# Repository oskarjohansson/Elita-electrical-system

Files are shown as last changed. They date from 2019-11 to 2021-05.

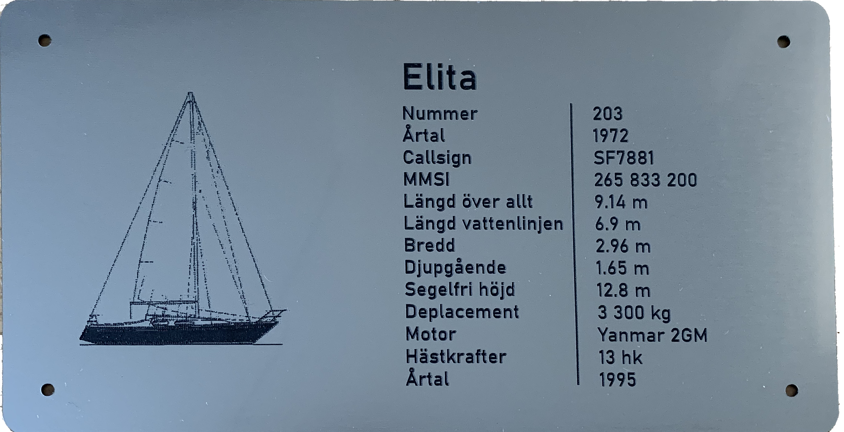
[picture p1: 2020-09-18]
hardware/control-panel/infosign.png

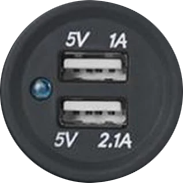
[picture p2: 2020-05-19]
hardware/control-panel/usb_outlet.png

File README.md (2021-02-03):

# Elita power distribution
> Created by Oskar Johansson 

This project is to refine the electrical system on the sailboat *Elita*. 

## Background

> A short background of the project. 

*Elita* was bought 2019 and had a relative good electrical system, but with poorly documentation. Since one of the complex part of a boat is the electrical system, the need of a reliable and easy system is important and there exists few power distribution system that is affordable. Then practical problems like have to wire everything through a panel to switch on and off seems quite old-fashioned.  

## Goal

> The goal of the project is 

The aim for this project is to simplify the wiring and make it possible for non-electrical-engineer to troubleshoot the system, like my brothers. 

The project will also aim to make it easier to do maintenance, like having a connector to all devices to make it easy to just unplug it without having to remove any cable. 

The project will also target one of the issues of the electrical system on a boat, the wire length. Since the voltage is 12 V, the voltage drop will affect the efficiency a lot when the wires become long. Together with that you want a control panel that is easily accessible the wiring become both long and complex. 

## Directories 

> The directories of the project. 

```python
Elita-electrical-system
├── documents                 # Manuals, ISO-documents, etc.       
│   └── datasheets            # Datasheet for components.
├── hardware                  # Schematics, pcbs, etc.
│   ├── battery-protection    # >100 A voltage protection for battery 
│   ├── cad                   # All CAD files 
│   ├── control-panel         # The control panel where all power switches are
│   ├── electrical-system     # Summary of the whole system
│   ├── flyback-protection    # To use in series of DC-motors to protect electrical system from flyback-currents.
│   ├── gerber                # Common folder for all gerber-files.
│   ├── ideal-diode           # An ideal diode circuit to charge the start battery everytime the bulk batteries is more charged.
│   ├── led-dimmer            # A simple dimmer for LED strips using a rotate encoder and mosfet
│   ├── libraries             # Project specific library.
│   ├── mount-panel           # A panel to mount the power distribution boards on.
│   ├── mppt-solar-charger    # A new controller to be used instead of the PWM controller.
│   ├── power-connector       # A simple power connector with M5 connectors. 
│   ├── power-distribution    			# Distribute power through mosfets and switches.
│   ├── power-distribution-complete		# Distribute all power through mosfets and switches.
│   ├── powersplitter         # In-line to split up the power-line.
│   ├── schematic             # All electrical schematics.
│   └── shorepower            # Schematic over how the shorepower should be connected according to complient ISO.
├── img                       # Images 
└── software                  # Firmwares
    └── led_dimmer            # Fiwmare for the led dimmer. 
```

# System 

> Here will the description of the system be. 

## Requirements

> The requirements of the system. 

- Follow ISO-standard, here ISO-10133 and ISO-13297
- Easy to use
- Lowest voltage drop possible
- No heat issue
- Integrated fuse
- Power meter 
- Easy to debug 
- Input from solar panel

## System architecture

> The architecture of the system. 

```python
├── Start battery           			# Must always be top charged.   
|	^
|	|
|	Ideal diode 						# To also charge the start battery from solar panel. 
|	^
|	|
└── House battery           			# Firmwares
    └── 120 A fuse          			# A resettable fuse
        ├── Fuse holder					# For things that shouldn't be switched off, like heater.
        |   └── Heater					# The heater has a cooldown process. 
	    └── Battery protection          # To protect from UV and be able to turn on/off from far away. 
	    	├── Fuse holder				# For things that has an integrated switch, like lighting. 
            |	├── Engine				# Everything that has to do with the engine.
            	|
                |
            |   └── Internal lights		# Has a switch on it.  
	    	└── Power distribution		# A fused power distribution with switches.
            	├── Navigation lights	
                |
                |
            	└── Refigerator 		  
```

> The power distribution of the system. 



## Subsystems

> Some of the sub sytem with the power consumption. 

| Subsystem | Power consumption | Need switch | Comment |
| --- | --- | --- | --- |
| Navigation lights | 3x15 W | Yes | |
| Motor lights | 1x15 W | Yes | |
| Anchor lights | 5 W | Yes | Doesn't exist yet. |
| Deck light | 35 W | Yes | |
| Cabin light | 40 W | Yes | Doesn't exist yet. |
| Stereo | 50 W | Yes | |
| Water pump | 35 W | Yes | |
| Refigerator | 50 W | Yes | |
| Septi pump | 50 W | Yes | |
| Instrument panel  | 100 W | Yes | VHF, Plotter, etc. |
| 12V + usb outlet  | 50 W | Yes | |
| Inverter 12/220V  | 600 W | Yes | Some 50 A relay maybe |
| Current meter | | No | Hall current meter |
| Voltage meter | | No | Should always be on |
| Switched light | 5x5 W + 15 W | No | Bedside, toilet and kitchen |
| Heater | 40 W | No | Has is own control panel |
| Solar panel | 50 W | No | Output from controller to battery. |

# Tips from different sources

> A list of different tips and link for more information. 

- Bigger cables closes to terminal
- Accessible battery switch
- Strict color coding!

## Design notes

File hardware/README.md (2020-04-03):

# Hardware

## Power distribution

### Schematic 


## Shore power

### Schematic 


## Flyback protection

### Schematic 


## Power splitter

### Schematic 


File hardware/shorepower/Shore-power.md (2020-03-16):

# Shore power 
This system is to be used at Elita, but can be implemented on a generic boat. The goal is to create a safe system which comply to ISO-standard for AC-installation in boats. 
## Specification
- 16A 
- Earthed CEE inlet
- Galvanic isolator
- 10/30 mA ground-fault  

## Links
- [DIN box, 1x4](https://www.clasohlson.com/se/Normkapsling/p/32-5006)
- [Fuse and safebrake combined](https://www.clasohlson.com/se/Personskyddsautomat/p/36-3094)
- [Galvanic isolator/Zink saver](https://www.biltema.se/bat/elutrustning/installationsmaterial/galvanisk-isolator-zink-saver-2000024139)
- LED indikator for connected 220V. 

## Information
- Protective conductor should be connected to DC negative

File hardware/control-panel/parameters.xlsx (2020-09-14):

wl_panel | 267 | mm | Left width of panel
wr_panel | 260 | mm | Right width of panel
l_panel | 630 | mm | Bottom length of panel
t_panel | 8 | mm | Thickness of panel
r_button | 8 | mm | Radius of power switch button
l_stereo | 183 | mm | Length of stereo
w_stereo | 53 | mm | Width of stereo
d_stereo | 177 | mm | Depth of stereo
w_label | 15 | mm | Label, ex Anchor light
l_label | 50 | mm | Bahnschrift Semibold 3,5mm
n_navlights | 4 | ul | Nav lights, anchor, motor, deck
r_labelscrew | 2.5 | mm
ro_labelscrew | 5 | mm
l_buttontobutton | 25 | mm | Space between buttons
n_interior | 6 | ul | Number of interior, cabin light, stereo etc
r_usboutlet | 29 | mm | Diameter of usboutlet
n_usboutlets | 4 | ul
l_fastener_button | 19 | mm
w_infosign | 100 | mm
l_infosign | 180 | mm
w_hidden_panel | 75 | mm | Part that is hidden by another piece

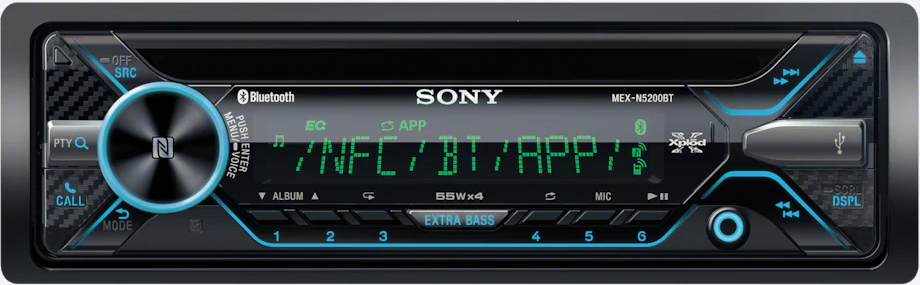
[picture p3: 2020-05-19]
hardware/control-panel/stereo.PNG

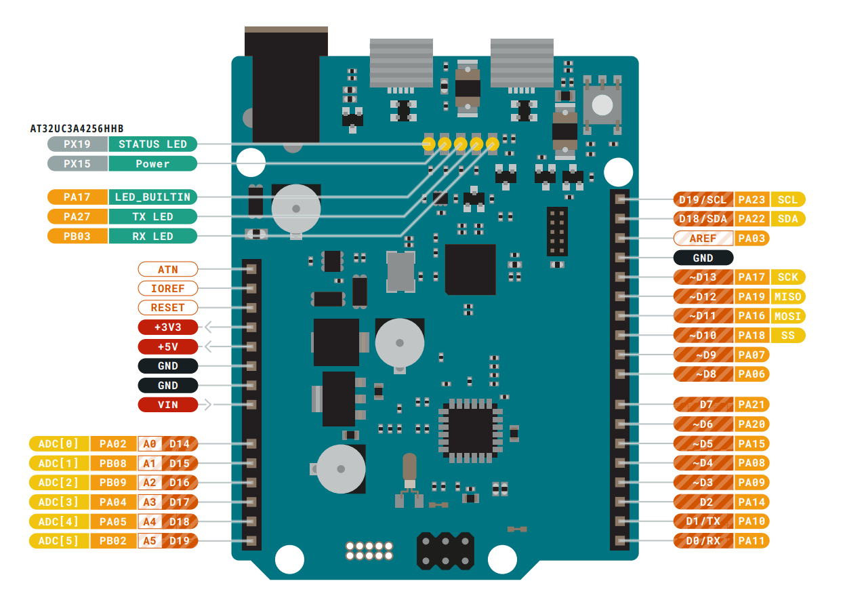
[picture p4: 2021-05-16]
hardware/led-dimmer/arduino_zero.png

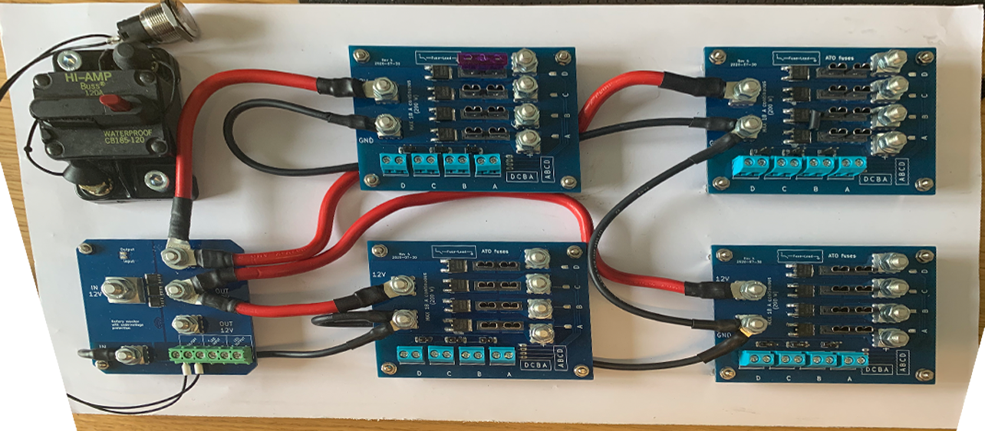
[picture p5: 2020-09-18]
img/system.png

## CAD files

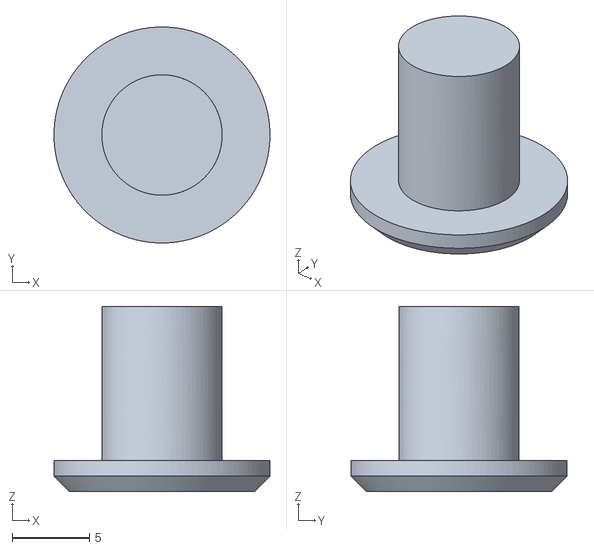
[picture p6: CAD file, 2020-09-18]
hardware/control-panel/dragswitch_top.stl
14.0 x 14.0 x 12.0

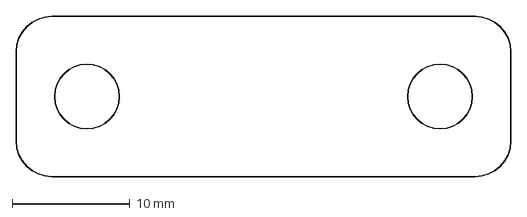
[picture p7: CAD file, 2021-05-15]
hardware/inline-dimmer/fuseMIDIOutline.dxf
42.0 x 13.6 mm

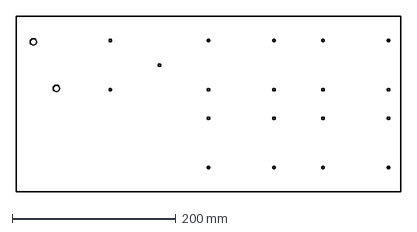
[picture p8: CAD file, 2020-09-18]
hardware/mount-panel/mount-panel-3.dxf
470.0 x 215.0 mm

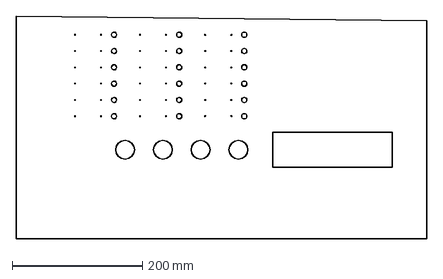
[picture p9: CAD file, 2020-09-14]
hardware/control-panel/wooden-panel.dxf
630.0 x 342.0 mm

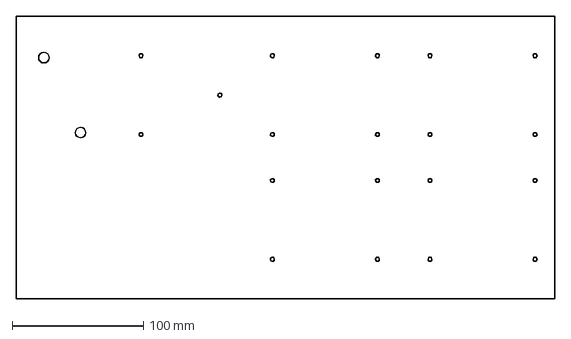
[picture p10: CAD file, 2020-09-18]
hardware/mount-panel/mount-panel-2.dxf
410.0 x 215.0 mm

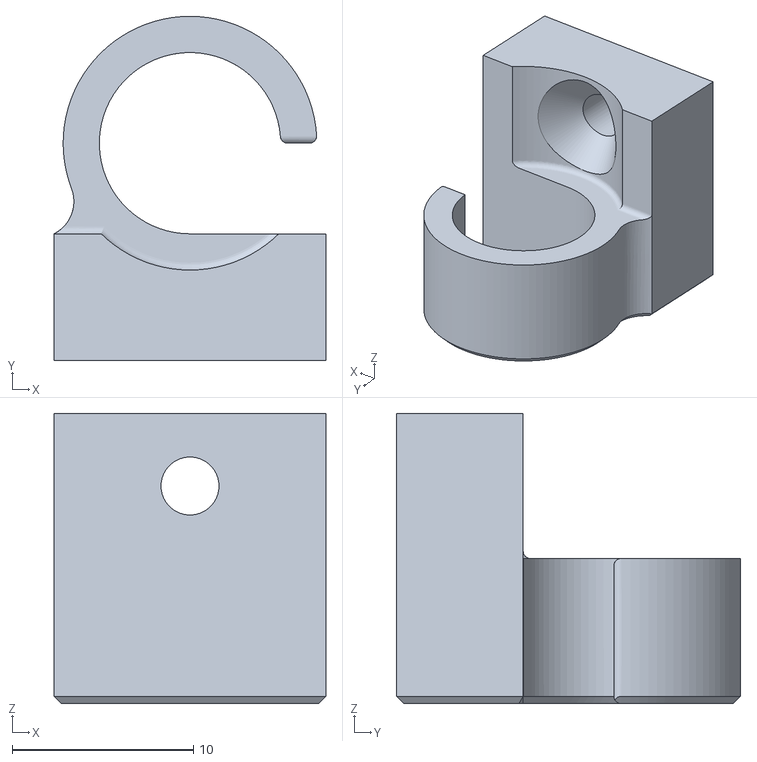
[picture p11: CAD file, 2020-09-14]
hardware/control-panel/cable_manager_open.stl
15.0 x 19.0 x 16.0

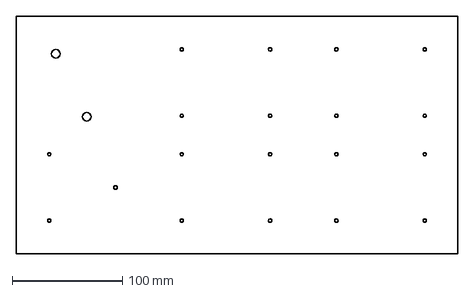
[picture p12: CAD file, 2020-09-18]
hardware/mount-panel/mount-panel.dxf
400.0 x 215.0 mm

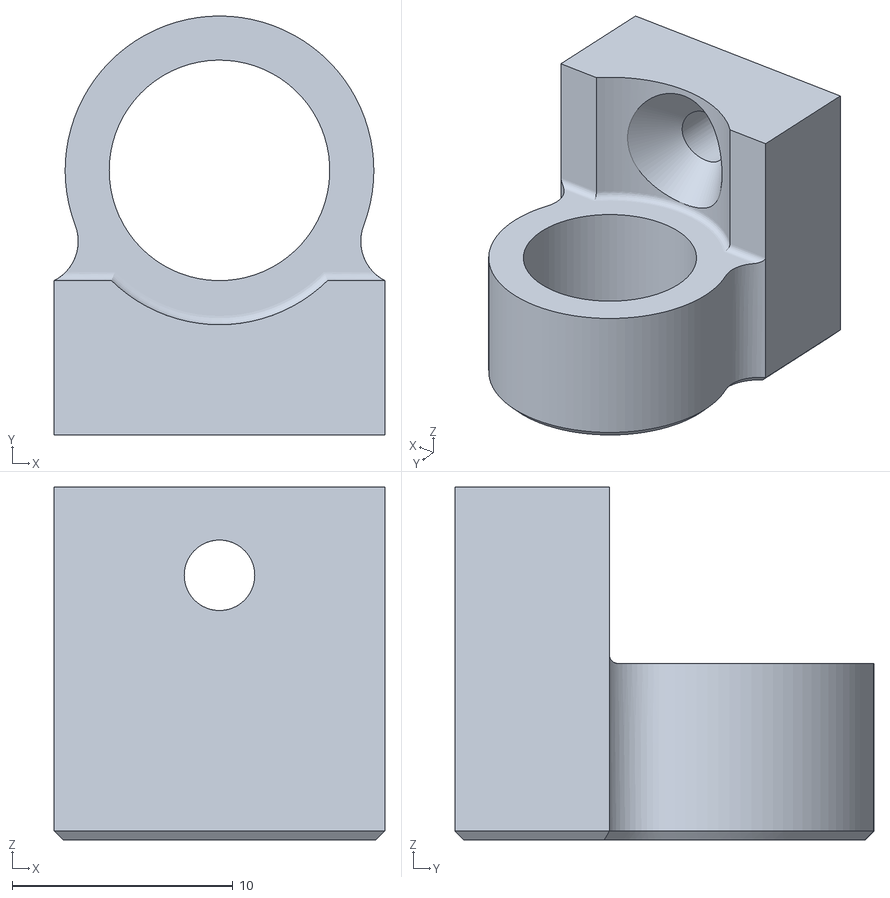
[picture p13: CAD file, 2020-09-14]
hardware/control-panel/cable_managerr.stl
15.0 x 19.0 x 16.0

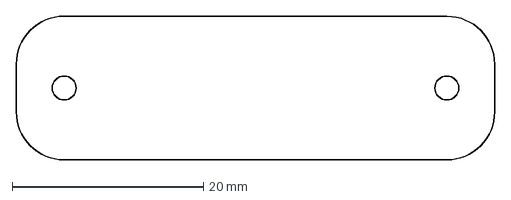
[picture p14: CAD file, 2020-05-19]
hardware/control-panel/label.dxf
50.0 x 15.0 mm

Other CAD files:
hardware/cad/COMPOUND.ipt
hardware/cad/COMPOUND_1.ipt
hardware/cad/COMPOUND_3.ipt
hardware/cad/Fastener.ipt
hardware/cad/Phoenix_pxc_1935161_04_PT-1-5-2-5-0-H_3D.iam
hardware/cad/Phoenix_pxc_1935187_04_PT-1-5-4-5-0-H_3D.iam
hardware/cad/PinHeader_1x02_P2.54mm_Vertical.iam
hardware/cad/Profileend_fasterner.ipt
hardware/cad/R_0603_1608Metric.iam
hardware/cad/SOLID.ipt
hardware/cad/SOLID_1.ipt
hardware/cad/SOLID_2.ipt
hardware/cad/TO-252-2.iam
hardware/cad/battery-protection/aluminium_block.ipt
hardware/cad/battery-protection/battery_protection_COMPOUND.ipt
hardware/cad/battery-protection/battery_protection_COMPOUND_1.ipt
hardware/cad/battery-protection/battery_protection_COMPOUND_2.ipt
hardware/cad/battery-protection/battery_protection_LED_0603_1608Metric.iam
hardware/cad/battery-protection/battery_protection_M5_7461383_rev1.iam
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

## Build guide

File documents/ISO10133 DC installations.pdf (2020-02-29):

Reference number
ISO 10133:2000(E)

© ISO 2000

# INTERNATIONAL STANDARD

# ISO

10133

Second edition
2000-12-01

## Small craft — Electrical systems — Extra-low-voltage d.c. installations

Petits navires — Systèmes électriques — Installations à très basse tension à courant continu

ISO 10133:2000(E)

PDF disclaimer
This PDF file may contain embedded typefaces. In accordance with Adobe's licensing policy, this file may be printed or viewed but shall not be edited unless the typefaces which are embedded are licensed to and installed on the computer performing the editing. In downloading this file, parties accept therein the responsibility of not infringing Adobe's licensing policy. The ISO Central Secretariat accepts no liability in this area.
Adobe is a trademark of Adobe Systems Incorporated.
Details of the software products used to create this PDF file can be found in the General Info relative to the file; the PDF-creation parameters were optimized for printing. Every care has been taken to ensure that the file is suitable for use by ISO member bodies. In the unlikely event that a problem relating to it is found, please inform the Central Secretariat at the address given below.

© ISO 2000
All rights reserved. Unless otherwise specified, no part of this publication may be reproduced or utilized in any form or by any means, electronic or mechanical, including photocopying and microfilm, without permission in writing from either ISO at the address below or ISO's member body in the country of the requester.
ISO copyright office
Case postale 56 CH-1211 Geneva 20
Tel. + 41 22 749 01 11
Fax + 41 22 749 09 47
E-mail copyright@iso.ch
Web www.iso.ch
Printed in Switzerland
ii | © ISO 2000 – All rights reserved

© ISO 2000 – All rights reserved | iii
Contents | Page

iv | © ISO 2000 – All rights reserved

## Foreword

ISO (the International Organization for Standardization) is a worldwide federation of national standards bodies (ISO member bodies). The work of preparing International Standards is normally carried out through ISO technical committees. Each member body interested in a subject for which a technical committee has been established has the right to be represented on that committee. International organizations, governmental and non-governmental, in liaison with ISO, also take part in the work. ISO collaborates closely with the International Electrotechnical Commission (IEC) on all matters of electrotechnical standardization.

International Standards are drafted in accordance with the rules given in the ISO/IEC Directives, Part 3.

Draft International Standards adopted by the technical committees are circulated to the member bodies for voting. Publication as an International Standard requires approval by at least 75 % of the member bodies casting a vote.

Attention is drawn to the possibility that some of the elements of this International Standard may be the subject of patent rights. ISO shall not be held responsible for identifying any or all such patent rights.

International Standard ISO 10133 was prepared by Technical Committee ISO/TC 188, Small craft.

This second edition cancels and replaces the first edition (ISO 10133:1994), of which it constitutes a technical revision.

Annexes A and B form a normative part of this International Standard. Annexes C and D are for information only.

© ISO 2000 – All rights reserved | v

## Introduction

Annex A specifies conductor requirements. Annex B specifies information and instructions to be included with the owner's manual (ISO 10240). Annex C provides information on recommended system tests to be performed upon completion of the d.c. installation.

This International Standard is intended to provide protection against explosion and fires. It is important to realize that this standard is not intended to achieve this purpose by itself. The manufacturer also needs to comply with additional standards related to protection against the same possible hazards. These additional standards are listed, in annex D, with a brief description of their contents. For complete understanding of the requirements, the manufacturer needs to refer to the actual standard. Compliance with all these International Standards will ensure a high level of safety in all craft, particularly in those using petrol or liquefied petroleum gas (LPG).

INTERNATIONAL STANDARD | ISO 10133:2000(E)
© ISO 2000 – All rights reserved | 1

Small craft — Electrical systems — Extra-low-voltage d.c.

## installations

### 1 Scope

This International Standard specifies the requirements for the design, construction and installation of extra-low-voltage direct current (d.c.) electrical systems which operate at nominal potentials of 50 V d.c. or less on small craft of hull length up to 24 m. Engine wiring as supplied by the engine manufacturer is not covered by this International Standard.

### 2 Normative references

The following normative documents contain provisions which, through reference in this text, constitute provisions of this International Standard. For dated references, subsequent amendments to, or revisions of, any of these publications do not apply. However, parties to agreements based on this International Standard are encouraged to investigate the possibility of applying the most recent editions of the normative documents indicated below. For undated references, the latest edition of the normative document referred to applies. Members of ISO and IEC maintain registers of currently valid International Standards.

ISO 6722-3: 1993, Road vehicles — Unscreened low-tension cables — Part 3: Conductor sizes and dimensions for thick-wall insulated cables.

ISO 6722-4: 1993, Road vehicles — Unscreened low-tension cables — Part 4: Conductor sizes and dimensions for thin-wall insulated cables.

ISO 8846:1990, Small craft — Electrical devices — Protection against ignition of surrounding flammable gases.

ISO 10239:—¹
, Small craft — Liquefied petroleum gas (LPG) systems.

ISO 10240:1995, Small craft — Owner’s manual.

ISO 13297:2000, Small craft — Electrical systems — Alternating current installations.

IEC 60529:1989, Degrees of protection provided by enclosures (IP Code).

IEC 60947-7-1:1989, Low-voltage switchgear and controlgear — Part 7: Ancillary equipment — Section One: Terminal blocks for copper conductors.

1 To be published.

2 © ISO 2000 – All rights reserved

### 3 Terms and definitions

For the purposes of this International Standard, the following terms and definitions apply.

3.1
equipotential bonding conductor
normally non-current-carrying conductor used to put various exposed conductive parts of direct current electrical devices and extraneous conductive parts at a substantially equal potential

3.2
engine negative terminal
terminal on the engine to which the negative battery cable is connected

3.3
craft's ground
craft's earth
ground (earth) which is established by a conducting connection (intended or accidental) with the common ground (potential of the earth's surface), including any conductive part of the wetted surface of the hull

3.4
ignition-protected equipment
equipment designed and constructed in accordance with ISO 8846

3.5
overcurrent protection device
device, such as a fuse or circuit-breaker, designed to interrupt the circuit when the current flow exceeds a predetermined value for a predetermined time

3.6
panel-board
switchboard
supporting panel on which are fixed devices for the purpose of controlling and/or distributing power on a craft

NOTE Examples of devices are circuit-breakers, fuses, switches, instruments and indicators.

3.7
sheath
uniform and continuous tubular protective covering of metallic or non-metallic material, generally extruded around one or more insulated conductors

EXAMPLES Moulded rubber, moulded plastics, woven sleeving or flexible tubing.

3.8
trip-free circuit-breaker
mechanical switching device capable of making, carrying and breaking currents under normal circuit conditions and also making, carrying for a specified time and breaking currents under specified abnormal circuit conditions, such as those of short circuit, and which is designed so that the resetting means cannot be manually held in place to override the current-interrupting mechanism

3.9
accessible
capable of being reached for inspection, removal or maintenance without removal of the permanent structure of the craft

3.10
readily accessible
capable of being reached quickly and safely for effective use without the use of tools

© ISO 2000 – All rights reserved | 3

3.11
conduit
part of a closed wiring system of circular or non-circular cross-section for insulated conductors and/or cables in electrical installations, allowing them to be drawn in and/or replaced

3.12
cable trunking
system of closed enclosures comprising a base with a removable cover intended for the complete surrounding of insulated conductors, cables or cords and for the accommodation of other electrical equipment

3.13
system voltage
nominal voltage supplied to the d.c. distribution panel-board (switchboard) from the power source

3.14
exposed conductive part
conductive part of electrical equipment, which can be touched and which is not normally live, but which may become live under fault conditions

3.15
fuse
device that, by fusing of one or more of its specifically designed and proportioned components, opens the circuit in which it is inserted by breaking the current when this exceeds a given value for a sufficient time.

NOTE The fuse comprises all the parts that form the complete device.

3.16
fully insulated two-wire d.c. system
system in which the d.c. negative is isolated from the ground (earth), i. e. not connected to the water through a metallic hull or the propulsion system, nor earthed through the a.c. protective conductor

3.17
two-wire d.c. system with negative ground
two-wire d.c. system with negative earth
system in which the d.c. negative is connected to the ground (earth) through a metallic hull, the propulsion system or other means

### 4 General requirements

4.1 The system type shall be either a fully insulated two-wire d.c. system or a two-wire d.c. system with a negative ground. The hull shall not be used as a current-carrying conductor. Engine-mounted wiring systems may use the engine block as the grounded conductor.

4.2 An equipotential bonding conductor, if fitted, shall be connected to the craft's ground (earth) to minimize stray current corrosion.

4.3 Switches and controls shall be marked to indicate their use, unless the purpose of the switch is obvious and its mistaken operation will not cause a hazardous condition.

4.4 Protective devices such as circuit-breakers or fuses shall be provided at the source of power, e. g. the panel-board (switchboard), to interrupt any overload current in the circuit conductors before heat can damage the conductor insulation, connections or wiring-system terminals.

The selection, arrangement and performance characteristics should be such that the following is achieved:

a) maximum continuity of service to healthy circuits under fault conditions through selective operation of the various protective devices;

4 © ISO 2000 – All rights reserved b) protection of electrical equipment and circuits from damage due to overcurrents, by coordination of the electrical characteristics of the circuit or apparatus and the tripping characteristics of the protective devices.

4.5 All d.c. equipment shall function over a voltage range at the battery terminals as follows:

| for a 12 volt system: 10,5 V to 15,5 V;
| for a 24 volt system: 21 V to 31 V.

Exception: Where the circuit includes equipment requiring a higher minimum voltage, the specified minimum voltage shall be used in the calculation of the conductor size. See clause A.2.

4.6 The length and cross-sectional area of conductors in each circuit shall be such that the calculated voltage drop shall not exceed 10 % of the nominal battery voltage for any appliance, when every appliance in the circuit is switched on at full load.

### 5 Batteries

5.1 Batteries shall be permanently installed in a dry, ventilated location above the anticipated bilge-water level.

5.2 Batteries shall be installed in a manner to restrict their movement horizontally and vertically considering the intended use of the craft, including trailering if applicable. A battery, as installed, shall not move more than 10 mm in any direction when exposed to a force corresponding to twice the battery weight.

5.3 The batteries installed in the craft shall be capable of inclinations of up to 30° without leakage of electrolyte. In monohull sailing craft, means shall be provided for containment of any spilled electrolyte up to inclinations of 45°.

5.4 Batteries shall be installed, designed or protected so that metallic objects cannot come into unintentional contact with any battery terminal.

5.5 Batteries, as installed, shall be protected against mechanical damage at their location or within their enclosure.

5.6 Batteries shall not be installed directly above or below a fuel tank or fuel filter.

5.7 Any metallic component of the fuel system within 300 mm above the battery top, as installed, shall be electrically insulated.

5.8 Battery cable terminals shall not depend on spring tension for mechanical connection to them.

### 6 Battery-disconnect switch

6.1 A battery-disconnect switch shall be installed in the positive conductor from the battery, or group of batteries, connected to the supply system voltage in a readily accessible location, as close as practical to the battery or group of batteries.

The following constitute exceptions:

a) outboard-powered craft with circuits for engine starting and navigation lighting only;
b) electronic devices with protected memory and protective devices such as bilge-pumps and alarms, if
| individually protected by a circuit-breaker or fuse as close as practical to the battery terminal;
c) ventilation exhaust blower of engine/fuel-tank compartment if separately protected by a fuse or circuit-breaker
| as close as practical to the battery terminal;

© ISO 2000 – All rights reserved | 5
d) charging devices which are intended to be used when the craft is unattended (e.g. solar panels, wind generators) if individually protected by a fuse or circuit-breaker as close as practical to the battery terminal.

6.2 The minimum continuous rating of the battery switch shall be at least equal to the maximum current for which the main circuit-breaker is rated and also the intermittent load of the starter motor circuit, or the current rating of the feeder conductor, whichever is less. A separate battery-disconnect switch may be installed for the engine-cranking motor circuit.

6.3 Remote-controlled battery-disconnect switches, if used, shall also permit safe manual operation.

### 7 Conductors

7.1 Electrical distribution shall use insulated stranded-copper conductors. See Table A.1. Conductor insulation shall be of fire-retardant material, e.g. not supporting combustion in the absence of flame.

7.2 Conductors that are not sheathed shall be supported throughout their length in conduits, cable trunking, or trays, or by individual supports at maximum intervals of 300 mm.

7.3 Sheathed conductors and battery conductors to the battery disconnect switch shall be supported at maximum intervals of 300 mm, with the first support not more than 1 m from the terminal. Other sheathed conductors shall be supported at maximum intervals of 450 mm.

Sheathed outboard-motor starter conductors constitute an exception to this requirement.

7.4 Conductors which may be exposed to physical damage shall be protected by sheaths, conduits or other equivalent means. Conductors passing through bulkheads or structural members shall be protected against damage to insulation by chafing.

7.5 Conductors shall have minimum dimensions in accordance with Table A.1, or the conductor manufacturer's rated current-carrying capacity, based on the load to be supplied and allowable voltage drop for the load to be carried. Conductors in voltage-critical circuits, such as starter motor circuits, navigation-light circuits and ventilation-blower circuits, whose output may vary with system voltage, shall be sized in compliance with the component manufacturer's requirements. See 4.5 and 4.6.

7.6 Each conductor longer than 200 mm installed separately shall have an area of at least 1 mm². Each conductor in a multi-conductor sheath shall have an area of at least 0,75 mm² and may extend out of the sheath a distance not to exceeding 800 mm.

An exception may be made for conductors of minimum area 0,75 mm² which may be used as internal wiring in panel-boards.

7.7 A d.c circuit shall not be contained in the same wiring system as an a.c. circuit, unless one of the following methods of separation is used.

a) For a multicore cable or cord, the cores of the d.c. circuit are separated from the cores of the a.c. circuit by an earthed metal screen of equivalent current-carrying capacity to that of the largest core in either circuit.
b) The cables are insulated for their system voltage and installed in a separate compartment of a cable ducting or trunking system.
c) The cables are installed on a tray or ladder where physical separation is provided by a partition.
d) A separate conduit, sheathing or trunking system is used.
e) The d.c and a.c. conductors are fixed directly to a surface and separated by at least 100 mm.

7.8 Each electrical conductor that is part of the electrical system shall have a means to identify its function in the system, except for conductors integral with engines as supplied by their manufacturers.

6 © ISO 2000 – All rights reserved

7.8.1 All equipotential bonding conductors shall be identified by green, or green with a yellow stripe, insulation, or may be uninsulated. Conductors with green, or green with a yellow stripe, insulation shall not be used for current-carrying conductors.

NOTE The protective conductor of the a.c. electrical system (see ISO 13297) also uses green, or green with a yellow stripe, insulation and may be connected to the d.c. negative terminal of the craft engine.

7.8.2 Means of identification other than colour for d.c. positive conductors is permitted if properly identified on the wiring diagram of the electrical system(s) of the craft.

7.8.3 All d.c. negative conductors shall be identified by black or yellow insulation. If the craft is equipped with an a.c. electrical system (see ISO 13297) which may use black insulation for live conductors, yellow insulation shall be used for d.c. negative conductors of the d.c. system. Black or yellow insulation shall not be used for d.c. positive conductors.

NOTE 1 | In conformance with IEC 60446, conductor insulation colours of the a.c. system are
| live conductors: black or brown;
| neutral conductors: white or light blue;
| protective conductors: green or green with a yellow stripe.
NOTE 2 | A colour stripe may be added to the conductor insulation for identification in the system.

Craft with a.c and d.c systems should avoid the use of a brown, white or light blue insulation colour in the d.c. system unless clearly separated from the a.c. conductors and identified (see 7.7).

7.8.4 Insulation-temperature ratings of conductors in engine spaces shall be 70 °C minimum. The conductors shall be rated oil resistant, or shall be protected by an insulating conduit or sleeving, and shall be derated in allowable current-carrying capacity in accordance with clause A.1.

7.8.5 For additional conductor specifications, see ISO 6722-3 and ISO 6722-4.

7.8.6 Current-carrying conductors of the d.c. system shall be routed above anticipated levels of bilge water and in other areas where water may accumulate, or at least 25 mm above the level at which the automatic bilge-pump switch activates.

If conductors must be routed in the bilge area, the wiring and connections shall be in an IP 67 enclosure, in accordance with IEC 60529, as a minimum, and there shall be no connection below the foreseeable water level.

7.8.7 Conductors shall be routed away from exhaust pipes and other heat sources which can damage the insulation.

The minimum clearance of the conductors is 50 mm from water-cooled exhaust components and 250 mm from dry exhaust components, unless an equivalent thermal barrier is provided.

### 8 Overcurrent protection

8.1 A manually reset trip-free circuit-breaker, or a fuse, shall be installed within 200 mm of the source of power for each circuit or conductor of the system or, if impractical, each conductor shall be contained within a protective covering, such as a sheathing conduit or cable trunking, for its entire length from the source of power to the circuit-breaker or fuse.

The following constitute exceptions.

a) The main power-feed circuit from the battery to an engine-cranking motor, if sheathed or supported to protect against abrasion and contact with conductive surfaces. See 7.2.

© ISO 2000 – All rights reserved | 7
b) The main power-feed from the battery to the panel-board (switchboard), distribution panel or fuse block, if sheathed or supported to protect against abrasion and contact with conductive surfaces. See 7.2.

If the fuse or circuit-breaker at the source of the supply conductor is sized to protect the smallest conductor in the circuit, only the fuse or circuit-breaker at the source is required.

8.2 The voltage rating of each fuse or circuit-breaker shall not be less than the nominal circuit voltage; the current rating shall not exceed the value for the conductor of smallest diameter in the circuit.

8.3 Output circuits of self-limiting generators and battery chargers do not require fuses or circuit-breakers.

### 9 Panel-boards (switchboards)

9.1 Panel-boards (switchboards) shall be installed such that the control elements, indicating instruments, circuit-breakers and fuses are readily accessible. The terminal side shall be accessible.

9.2 Connections and components on panel-boards shall be in locations protected from the expected conditions in conformity with IEC 60529:

| IP 67 as a minimum, if exposed to short-term immersion;
| IP 55 as a minimum, if exposed to splashing water;
| IP 20 as a minimum, if located in protected locations inside the craft.

9.3 Panel-boards (switchboards) shall be permanently marked with the nominal system voltage.

EXAMPLE 12 V d.c. (or 6 V d.c., 24 V d.c., 32 V d.c., as appropriate for the craft)

9.4 Craft equipped with both direct current (d.c.) and alternating current (a.c.) electrical systems shall have their distribution from either separate panel-boards or a common one with a partition or other positive means provided to separate clearly the a.c. and d.c. sections from each other. Wiring diagrams to identify circuits, components and conductors shall be included, with the craft.

### 10 Wiring connections and terminals

10.1 Conductor connections shall be in locations protected from the weather or in IP 55 enclosures, in accordance with IEC 60529 as a minimum. Connections above deck exposed to intermittent immersion shall be in IP 67 enclosures, in accordance with IEC 60529 as a minimum.

10.2 Metals used for terminal studs, nuts and washers shall be corrosion resistant and galvanically compatible with the conductor and terminal. Aluminium and unplated steel shall not be used for studs, nuts or washers in electrical circuits.

10.3 All conductors shall have suitable terminals installed, i.e. no bare wires attached to stud or screw connections.

10.4 Screw-clamp or screwless terminal blocks shall conform to IEC 60947-7-1. Other terminals shall be of the ring or self-locking captive-spade type, not dependent on screw or nut tightness alone for retention on the stud or screw.

An exception is that friction-type connectors may be used in circuits not exceeding 20 A if the connection does not separate when subjected to a force of 20 N.

10.5 Twist-on connectors (wire nuts) shall not be used.

8 © ISO 2000 – All rights reserved

10.6 Exposed shanks of terminals shall be protected against accidental shorting by the use of insulating barriers or sleeves, except for those in the grounding system.

10.7 Solderless crimp-on terminals and connectors shall be attached with the type of crimping tool designed for the termination used and for a connection meeting the following requirements.

Each conductor-to-connector and conductor-to-terminal connection shall be capable of withstanding a tensile force equal to at least the value shown in Table 1 for the smallest conductor in the connection, without separating.

Table 1 — Tensile values for connectors

Conductor size mm² | Tensile force N | Conductor size mm² | Tensile force N | Conductor size mm² | Tensile force N
0,75 1 1,5 2,5 4 | 40 60 130 150 170 | 6 10 16 25 35 | 200 220 260 310 350 | 50 70 95 120 150 | 400 440 550 660 770

10.8 No more than four conductors shall be secured to one terminal stud.

### 11 Receptacles/sockets

11.1 Receptacles/sockets and matching plugs used on d.c. systems shall not be interchangeable with those used on a.c. systems on the craft.

11.2 Receptacles/sockets installed in locations subject to rain, spray or splashing shall have a minimum protection of IP 55, in accordance with IEC 60529 when not in use, e.g. protected by a cover with an effective weatherproof seal.

11.3 Receptacles/sockets installed in areas subject to flooding or momentary submersion shall have a minimum protection of IP 67, in accordance with IEC 60529, including when in use with connecting plugs.

### 12 Ignition protection

12.1 Electrical components installed in compartments which may contain explosive vapour and gases shall be ignition-protected in accordance with ISO 8846.

Compartments which may contain explosive gases are those containing, or which have open connections with compartments containing, such items as

a) spark-ignition engines or their fuel tanks;
b) joints or fittings in fuel lines connecting spark-ignition engines with their fuel tanks.

Open compartments having 0,34 m² of open area per cubic metre of compartment volume exposed to the open atmosphere outside the craft constitute an exception to this requirement.

12.2 Electrical components installed in certain compartments in craft with liquefied petroleum gas (LPG) systems, such as lockers and housings containing LPG cylinders and pressure regulators, shall be ignition-protected (see ISO 8846) as required in ISO 10239.

© ISO 2000 – All rights reserved | 9

## Annex A (normative)

## Conductor requirements

A.1 Table A.1 gives allowable continuous current ratings, in amperes, determined for an ambient temperature of 30 °C, and the minimum number of strands for conductors.

For conductors in engine rooms (60 °C ambient), the maximum current rating in Table A.1 shall be derated by the factors listed below:

Temperature rating of conductor insulation: | Multiply maximum current from Table A.1 by:
70 °C
85 °C to 90 °C
105 °C
125 °C
200 °C

0,75
0,82
0,86
0,89
1
A.2 As a guideline, the voltage drop E at load, in volts, may be calculated by the following formula:
0,016 4 IL E | S

where

S | is the cross-sectional area of the conductor, in square millimetres;
I | is the load current, in amperes;
L | is the length, in metres, of the conductor from the positive power source to the electrical device and back
to the negative source connection.

10 © ISO 2000 – All rights reserved

Table A.1 — Cross-sectional area of conductor, allowable continuous current and stranding

Cross-sectional
area

Maximum current, in amperes, for single conductors at insulation temperature ratings

Minimum number
of strands
mm² | 60 °C | 70 °C | 85 °C to 90 °C | 105 °C | 125 °C | 200 °C | Type A | Type B
0,75 | 6 | 10 | 12 | 16 | 20 | 25 | 16 | —
1 | 8 | 14 | 18 | 20 | 25 | 35 | 16 | —
1,5 | 12 | 18 | 21 | 25 | 30 | 40 | 19 | 26
2,5 | 17 | 25 | 30 | 35 | 40 | 45 | 19 | 41
4 | 22 | 35 | 40 | 45 | 50 | 55 | 19 | 65
6 | 29 | 45 | 50 | 60 | 70 | 75 | 19 | 105
10 | 40 | 65 | 70 | 90 | 100 | 120 | 19 | 168
16 | 54 | 90 | 100 | 130 | 150 | 170 | 37 | 266
25 | 71 | 120 | 140 | 170 | 185 | 200 | 49 | 420
35 | 87 | 160 | 185 | 210 | 225 | 240 | 127 | 665
50 | 105 | 210 | 230 | 270 | 300 | 325 | 127 | 1 064
70 | 135 | 265 | 285 | 330 | 360 | 375 | 127 | 1 323
95 | 165 | 310 | 330 | 390 | 410 | 430 | 259 | 1 666
120 | 190 | 360 | 400 | 450 | 480 | 520 | 418 | 2 107
150 | 220 | 380 | 430 | 475 | 520 | 560 | 418 | 2 107
Conductors with at least Type A stranding shall be used for general wiring of the craft. Conductors with Type B stranding shall be used for any wiring where frequent flexing is involved during use.
NOTE Conductor current ratings may be interpolated for cross-sectional areas between those shown above.

© ISO 2000 – All rights reserved | 11

## Annex B (normative)

## Information and instructions to be included with owner's manual (ISO 10240)

B.1 The following information shall be included with the owner's manual:

a) diagram(s) identifying the electrical circuits of the craft with the locations of electrical devices in the craft and identification of conductors by colour or other means;
b) location and description of functions of electrical controls, dials, switches, fuses and also circuit-breakers installed on the panel-board.

B.2 The following warning instructions shall be provided for the owner.

Never

a) work on the electrical installation while the system is energized;
b) modify the craft’s electrical system or relevant drawings: installation, alterations and maintenance should be performed by a competent marine electrical technician;
c) alter or modify the rated current amperage of overcurrent protective devices;
d) install or replace electrical appliances or devices with components exceeding the rated current amperage of the circuit;
e) leave the craft unattended with the electrical system energized, except automatic bilge-pump, fire protection and alarm circuits.

12 © ISO 2000 – All rights reserved

## Annex C (informative)

## Recommended system tests

The following system tests should be performed upon completion of the d.c. installation.

| Continuity test of circuits, particularly ring and protective circuits.
| Insulation resistance testing at 500 V d.c. for each circuit.

CAUTION — Some electronic equipment may be damaged by high d.c. voltages.

© ISO 2000 – All rights reserved | 13

## Annex D (informative)

## Related standards and brief description of their contents

This International Standard is intended to provide protection against explosion and fires. It is important to realize that this standard is not intended to achieve this purpose by itself. The manufacturer also needs to comply with additional Standards related to protection against the same possible hazards. These additional standards are listed in annex D, with a brief description of their contents. For complete understanding of the requirements, the manufacturer needs to refer to the actual standard. Compliance with all these International Standards will ensure a high level of safety in all craft, particularly in those using petrol or liquefied petroleum gas (LPG).

[1] ISO 10088:—²
, Small craft — Permanently installed fuel systems and fixed fuel tanks.

Individual fuel tanks, 100 % pressure tested
Non-metallic fuel tanks, fire tested
Fire-resistant flexible fuel hoses
Fire test for non-metallic fuel-system components Corrosion-resistant fuel-tank materials Galvanically compatible metallic parts Anti-siphon protection requirements
Double clamping of fuel-fill hoses
Electrically ground (earth) major metallic parts
100 % pressure test of entire fuel system
[2] ISO 8846:1990, Small craft — Electrical devices — Protection against ignition of surrounding flammable gases.

All components in petrol engines, petrol and LPG tank compartments to be ignition-protected to prevent open sparks. This applies to the entire engine, as well as all electrical contacts, commutators, brushes, collector rings, switches, relays, generators, fuses, distributors, engine-cranking motors, propulsion-trim motors, etc.

ISO 8846 further requires components to withstand any operating conditions of the device, including the maximum achievable overload up to 400 % of the rated current (circuit-breakers, switches and the like) and a stalled rotor condition for any motor with the circuit protected in an overcurrent protective device specified by the product manufacturer.

[3] ISO 7840:1994, Small craft — Fire-resistant fuel hoses.

Only fire-resistant fuel hoses may be used in petrol engine and petrol fuel-tank compartments. A flexible hose to be used between the engine and any solidly mounted metallic line to eliminate vibration failure. The hose to withstand fire, pressure, vacuum collapse, ozone and other environments, and have minimal fuel permeation.

[4] ISO 9097:1991, Small craft — Electric fans.
[5] ISO 8849:1990, Small craft — Electrically operated bilge-pumps.

All components, if installed in a petrol engine, petrol or LPG tank compartment to be ignition-protected, have all wiring insulated, be suitable for marine environment, and not create a hazard when the motor is overloaded or stalled.

2 To be published. (Revision of ISO 10088:1992)

14 © ISO 2000 – All rights reserved

[6] ISO 10239:—³
, Small craft — Liquefied petroleum gas (LPG) systems.

System to withstand temperature extremes
Appliances approved and installed only in ventilated compartments, tanks and pressure regulators in lockers identified and vented with overboard drains
Meet specifications for fuel lines and their supports
Appliance well secured with flame-failure shutoff control device for each appliance
Warning labels on appliances
Pressure test on installed system
Any electrical device in lockers, designated for LPG storage, ignition-protected
[7] ISO 9094-1:—³⁾, Small craft — Fire protection — Part 1: Craft with a hull length of up to and including 15 m.

ISO 9094-2:—³⁾, Small craft — Fire protection — Part 2: Craft with a hull length of more than 15 m and up to and including 24 m.

Specifications for exits and emergency exits
Material specifications in areas close to open flames
Self-extinguishing materials in engine compartment Ventilation and flue protection for water heater
Sealed combustion systems on unattended appliances
Specification for fuel tanks
Requirement for portable fire-extinguishers, for accessibility, protection, stowage and locker identification size
Specification for number and types of fire-extinguishers
Specification for fixed fire-extinguishing system on some craft
Cylinder installation specification
Remote release for fixed systems
Distribution hoses and tubes, fire-resistant
Specifications for discharge and control
Discharge and operating instructions
[8] ISO 11105:1997, Small craft — Ventilation of petrol engine and/or petrol tank compartments.

Ventilation amount based on compartment volume
Specification for compartment tightness
Natural and powered ventilation in engine compartments
Natural ventilation in certain fuel compartments
Ventilation openings on exterior of craft
Blower warning for craft operator
[9] IEC 60092-350:1988, Electrical installations in ships — Part 350: Low-voltage shipboard power cables. General construction and test requirements.
[10] IEC 60092-352:1979, Electrical installations in ships — Part 352: Choice and installation of cables for low-voltage power systems.
[11] IEC 60446:1999, Basic and safety principles for man-machine interface, marking and identification — Identification of conductors by colours or numerals.

3 To be published.

ICS 47.080
Price based on 14 pages

© ISO 2000 – All rights reserved

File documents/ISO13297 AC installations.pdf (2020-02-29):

Reference number
ISO 13297:2000(E)

© ISO 2000

# INTERNATIONAL STANDARD

# ISO

13297

Second edition
2000-12-01

## Small craft — Electrical systems — Alternating current installations

Petits navires — Systèmes électriques — Installations de distribution de courant alternatif

ISO 13297:2000(E)

PDF disclaimer
This PDF file may contain embedded typefaces. In accordance with Adobe's licensing policy, this file may be printed or viewed but shall not be edited unless the typefaces which are embedded are licensed to and installed on the computer performing the editing. In downloading this file, parties accept therein the responsibility of not infringing Adobe's licensing policy. The ISO Central Secretariat accepts no liability in this area.
Adobe is a trademark of Adobe Systems Incorporated.
Details of the software products used to create this PDF file can be found in the General Info relative to the file; the PDF-creation parameters were optimized for printing. Every care has been taken to ensure that the file is suitable for use by ISO member bodies. In the unlikely event that a problem relating to it is found, please inform the Central Secretariat at the address given below.

© ISO 2000
All rights reserved. Unless otherwise specified, no part of this publication may be reproduced or utilized in any form or by any means, electronic or mechanical, including photocopying and microfilm, without permission in writing from either ISO at the address below or ISO's member body in the country of the requester.
ISO copyright office
Case postale 56 CH-1211 Geneva 20
Tel. + 41 22 749 01 11
Fax + 41 22 749 09 47
E-mail copyright@iso.ch
Web www.iso.ch
Printed in Switzerland
ii | © ISO 2000 – All rights reserved

© ISO 2000 – All rights reserved | iii
Contents | Page

iv | © ISO 2000 – All rights reserved

## Foreword

ISO (the International Organization for Standardization) is a worldwide federation of national standards bodies (ISO member bodies). The work of preparing International Standards is normally carried out through ISO technical committees. Each member body interested in a subject for which a technical committee has been established has the right to be represented on that committee. International organizations, governmental and non-governmental, in liaison with ISO, also take part in the work. ISO collaborates closely with the International Electrotechnical Commission (IEC) on all matters of electrotechnical standardization.

International Standards are drafted in accordance with the rules given in the ISO/IEC Directives, Part 3.

Draft International Standards adopted by the technical committees are circulated to the member bodies for voting. Publication as an International Standard requires approval by at least 75 % of the member bodies casting a vote.

Attention is drawn to the possibility that some of the elements of this International Standard may be the subject of patent rights. ISO shall not be held responsible for identifying any or all such patent rights.

International Standard ISO 13297 was prepared by Technical Committee ISO/TC 188, Small craft.

This second edition cancels and replaces the first edition (ISO 13297:1995), of which it constitutes a technical revision.

Annex A and B form a normative part of this International Standard. Annexes C and D are for information only.

© ISO 2000 – All rights reserved | v

## Introduction

Annex A specifies conductor requirements. Annex B specifies instructions to be included with the owner's manual (ISO 10240). Annex C provides information on recommended system tests to be performed upon completion of the a.c. installation.

Compliance with this International Standard will not, by itself, provide protection against explosion, fire and electrical shock hazard. The manufacturer also needs to comply with additional standards related to protection against the same possible hazards. These additional standards are listed in annex D, with a brief description of their contents. For complete understanding of the requirements, the manufacturer needs to refer to the actual standard. Compliance with all these International Standards will ensure a high level of safety in all craft, particularly in those using petrol or liquefied petroleum (LPG).

INTERNATIONAL STANDARD | ISO 13297:2000(E)
© ISO 2000 – All rights reserved | 1

## Small craft — Electrical systems — Alternating current installations

### 1 Scope

This International Standard specifies the requirements for the design, construction and installation of low-voltage alternating current electrical systems which operate at nominal voltages of less than 250 V single phase on small craft of hull length up to 24 m.

NOTE This International Standard does not cover three-phase installations.

### 2 Normative references

The following normative documents contain provisions which, through reference in this text, constitute provisions of this International Standard. For dated references, subsequent amendments to, or revisions of, any of these publications do not apply. However, parties to agreements based on this International Standard are encouraged to investigate the possibility of applying the most recent editions of the normative documents indicated below. For undated references, the latest edition of the normative document referred to applies. Members of ISO and IEC maintain registers of currently valid International Standards.

ISO 8846:1990, Small craft — Electrical devices — Protection against ignition of surrounding flammable gases.

ISO 9094-1:—¹
| , Small craft — Fire protection — Part 1: Craft with a hull length of up to and including 15 m.

ISO 10133:2000, Small craft — Electrical systems — Extra-low-voltage d.c. installations.

ISO 10240:1995, Small craft — Owner’s manual.

IEC 60079-0:1998, Electrical apparatus for explosive gas atmospheres — Part 0: General requirements.

IEC 60446:1999, Basic and safety principles for non-machine interface marking and identification — Identification of conductors by colours or numerals.

IEC 60529:1989, Degrees of protection provided by enclosures (IP code).

IEC 60947-7-1:1989, Low-voltage switchgear and controlgear — Part 7: Ancillary equipment — Section One: Terminal blocks for copper conductors.

### 3 Terms and definitions

For the purposes of this International Standard, the following terms and definitions apply.

1 To be published.

2 © ISO 2000 – All rights reserved

3.1
craft's ground
craft's earth
ground (earth) which is established by a conducting connection (intended or accidental) with the common ground (potential of the earth's surface), including any conductive part of the wetted surface of the hull

3.2
residual (differential) current device
ground-fault circuit interrupter
RCD
GFCI
electromechanical switching device, or association of devices, designed to make, carry and break currents under normal service conditions and to cause the opening of contacts when the residual current attains a given value under specified conditions

NOTE RCD/GFCI serve to reduce the risk of injury to people from electrical shock.

3.3
polarization transformer
transformer which automatically orientates the neutral and live conductors in the system in the same polarity orientation as the polarized system of the craft

3.4
isolation transformer
transformer with protective separation between the input and output windings and the protective conductor

3.5
neutral conductor
conductor connected to the neutral point of a system and capable of contributing to the transmission of electrical energy

3.6
protective earthing conductor
protective grounding conductor
conductor, not normally carrying current, used for some measure of protection against electric shock, for electrically connecting any of the following parts of electrical equipment to the craft's ground (earth) and to the shore a.c. grounding conductor through the shore-power cable:
a) exposed conductive parts of electrical equipment;
b) extraneous conductive parts;
c) the main grounding (earthing) terminal;
d) earth electrode(s);
e) the earth point of a source, or an artificial neutral.

3.7
live conductor
conductor or conductive part intended to be energized in normal use, including a neutral conductor

3.8
ignition-protected equipment
equipment designed and constructed to comply with ISO 8846

© ISO 2000 – All rights reserved | 3

3.9
overcurrent protection device
device, such as a fuse or circuit-breaker, designed to interrupt the circuit when the current flow exceeds a predetermined value for a predetermined time

3.10
panel-board
switchboard
assembly of devices for the purpose of controlling and/or distributing electrical power

NOTE Examples of devices are circuit-breakers, fuses, switches, instruments and indicators.

3.11
polarized system
system in which the neutral and live conductors are connected in the same manner to all terminals on devices or receptacles (socket outlets) in a circuit

3.12
shore-power inlet
fitting designed for mounting on a craft, of a shrouded male type, to connect to the female connector on the craft end of the shore-power cable, in order to make the electrical connection for transmission of electrical energy

3.13
trip-free circuit-breaker
mechanical switching device capable of making, carrying and breaking currents under normal circuit conditions and also making, carrying for a specified time and breaking currents under specified abnormal circuit conditions, such as those of overload or short circuit, and which are designed so that the resetting means cannot be manually held in place to override the current-interrupting mechanism

3.14
accessible
capable of being reached for inspection, removal or maintainance without removal of the permanent structure of the craft

3.15
readily accessible
capable of being reached quickly and safely for effective use without the use of tools

3.16
sheath
uniform and continuous protective tubular covering of metallic or non-metallic material around one or more insulated conductors

EXAMPLES Moulded rubber, moulded plastic, woven sleeving or flexible tubing.

3.17
conduit
part of a closed wiring system of circular or non-circular cross-section for insulated conductors and/or cables in electrical installations, allowing them to be drawn in and/or replaced

3.18
cable trunking
system of closed enclosures comprising a base with a removable cover intended for the complete surrounding of insulated conductors, cables or cords and for the accommodation of other electrical equipment

3.19
double-pole circuit-breaker
device intended to interrupt both the neutral and live conductors in a circuit simultaneously when a designated current is exceeded for a predetermined time

4 © ISO 2000 – All rights reserved

3.20
captive-spade terminal
conductor terminal component which is maintained in the connection to the screw or stud even when the threaded terminal fastener is loose

3.21
exposed conductive part
conductive part of electrical equipment, which can be readily touched and which is not normally live, but which may become live under fault conditions

3.22
fuse
device that, by fusing of one or more of its specifically designed and proportioned components, opens a circuit in which it is inserted by breaking the current when this exceeds a given value for a sufficient time

NOTE The fuse comprises all the parts that form the complete device.

3.23
galvanic isolator
device installed in series with the a.c. protective conductor of the shore-power cable to block low-voltage d.c. galvanic current flow, but permit the passage of alternating current normally associated with the protective conductor

### 4 General requirements

4.1 The protective conductor insulation shall be green or green with a yellow stripe. Neither colour shall be used for current-carrying conductors.

NOTE The equipotential bonding conductor of the d.c. electrical system (see ISO 10133) also uses green, or green with a yellow stripe, insulation and is connected to various exposed conductive parts of direct-current electrical devices, other extraneous conductive parts and the d.c. negative ground/earth.

4.2 The protective conductor shall be connected to the craft's d.c. negative ground (earth) as close as practicable to the battery (d.c.) negative terminal.

NOTE If an RCD (whole-craft residual current device) or an isolation transformer is installed in the main supply circuit of the a.c. system (see 8.2), the negative ground terminal of the d.c. system need not be connected to the a.c. shore ground (protective conductor).

4.3 For craft with fully insulated d.c. systems (see ISO 10133), the a.c. protective conductor shall be connected to the hull of a metallic hull craft, the craft external ground (earth) or the craft lightning-protection ground plate, if fitted.

4.4 Metallic craft hulls shall not be used as conductors.

4.5 The protective conductor shall be connected to metallic hulls at a location above any anticipated water accumulation.

4.6 Individual circuits shall not be capable of being energized by more than one source of electrical power at a time. Each shore-power inlet, generator or inverter is a separate source of electrical power. The transfer from one power-source circuit to another shall be made by a means which opens all current-carrying conductors, live and neutral, before closing the other source circuit, prevents arc-over between contacts and is interlocked by mechanical or electromechanical means. Both current-carrying conductors, live and neutral, shall be broken simultaneously when changing power sources.

4.7 Energized parts of electrical equipment shall be guarded against accidental contact by the use of enclosures of at least IP 2X type, in accordance with IEC 60529, or other protective means which shall not be used for non-electrical equipment. Access to energized parts of the electrical system shall require the use of hand tools or have a protection of at least IP 2X, unless otherwise specified. A suitable warning sign shall be displayed (see 5.2).

© ISO 2000 – All rights reserved | 5

4.8 The neutral conductor shall be grounded (earthed) only at the source of power, i.e. at the onboard generator, the secondary of the isolation or polarization transformer, or the shore-power connection. The shore-power neutral shall be grounded through the shore-power cable and shall not be grounded on board the craft.

4.9 A galvanic isolator or other suitable device may be fitted in the protective conductor to resist imported stray galvanic current flow while permitting the passage of a.c. current, if present. Galvanic isolators shall be designed to withstand the application of power from a short-circuit test from a source capable of delivering 5 000 A r.m.s. symmetrically to its output test terminals for the time required for the circuit-breaker in the test circuit to trip. After three applications of the short-circuit test, the electrical and mechanical characteristics of the isolator shall be unchanged.

### 5 Marking

5.1 Shore-power inlets shall be marked to indicate voltage, current, shock hazard symbol | and read owner's
manual symbol | .

5.2 A permanently mounted waterproof warning sign shall be located at the panel-board on the craft. The sign shall include the information shown in Figure 1a) or 1b).

Warning | Electrical shock hazard | Fire hazard | Read owner's manual
a) Suggested warning sign using symbols

WARNING — To minimize shock and fire hazards:
1) Turn off craft's shore-power connection switch before connecting or disconnecting shore-power cable.
2) Connect shore-power cable to craft's inlet before connecting to shore-power source.
3) If polarity indicator is activated, immediately disconnect cable.
4) Disconnect shore-power cable at shore-power source first.
5) Close shore-power inlet cover tightly.
DO NOT ALTER SHORE-POWER CABLE CONNECTORS.
b) Suggested warning sign with text in language appropriate to the country of use

Figure 1 — Suggested warning signs

NOTE In Figure 1 b), item 3 is required only if a polarity indicator is installed in the system and items 2, 4 and 5 are not required for permanently connected shore-power cable installations.

5.3 Switches and controls shall be marked to indicate their function, unless the purpose of the switch is obvious and if operation of the switch could not, under normal operating conditions, cause a hazardous condition.

6 © ISO 2000 – All rights reserved

### 5.4 Electrical equipment shall be marked or identified to indicate:

a) manufacturer's identification;
b) model number or designation;
c) electrical rating in volts and amperes, or volts and watts;
d) phase and frequency, if applicable;
e) ignition protected, if applicable, by ISO 8846.

### 6 Ignition sources

Electrical components installed in compartments which, in normal operation, may contain liquefied petroleum gases (LPG) or petrol vapour, e.g. petrol tank, engine compartment and LPG lockers, shall be designed to be compliant with ISO 8846 or in accordance with IEC 60079-0, and shall be located in accordance with ISO 9094-1.

### 7 Overcurrent protection

### 7.1 General requirements

7.1.1 In unpolarized systems, double-pole circuit-breakers that open both live and neutral conductors are required.

7.1.2 Fuses shall not be installed in unpolarized systems.

7.1.3 Overcurrent protection devices for motor loads shall have a predetermined value of current flow that is consistent with demand-load characteristics of the protected circuit.

7.1.4 All a.c. motor installations and each motor of a motor-operated device shall be individually protected in accordance with 7.1.3 by an integral overcurrent or thermal protection device.

An exception may be made for motors that will not overheat under continuous locked-rotor conditions.

7.1.5 The rating of the overcurrent protection device shall not exceed the maximum current-carrying capacity of the conductor being protected. See Table A.1.

### 7.2 Main supply circuits

7.2.1 Double-pole circuit-breakers shall be installed in conductors to the shore-power supply circuits.

7.2.2 A manually reset trip-free circuit-breaker shall be installed within 0,5 m of the source of power or, if impractical, the conductor from the source of power to the panel-board circuit-breaker shall be contained within a protective covering, such as a junction box, control box, enclosed panel-board, or within a conduit or cable trunking or equivalent protective covering. If the location of the main shore-power inlet circuit-breaker exceeds 3 m from the shore-power inlet connection or the electrical attachment point of a permanently installed shore-power cord, additional fuses or circuit-breakers shall be provided within 3 m of the inlet or attachment point to the electrical system in the craft, measured along the conductor.

7.2.3 Overcurrent protection shall be provided for isolation and polarization transformers, including a bank of transformers operating as a unit. Each transformer shall be protected by an individual overcurrent device on the primary side, rated at not more than 125 % of the rated primary current of the transformer.

© ISO 2000 – All rights reserved | 7

### 7.3 Branch circuits

7.3.1 The live conductor of each branch-circuit in a polarized system shall be provided with overcurrent protection, i.e. a fuse or circuit-breaker, at the point of connection to the main panel-board bus.

7.3.2 Both conductors of each branch circuit in unpolarized systems shall be provided with overcurrent protection by double-pole circuit-breakers and double-pole switches, if used, at the point of connection to the main panel-board bus.

### 8 Ground-fault protection/earth-leakage protection

8.1 GFCIs (RCDs) shall be of the trip-free type.

8.2 The craft shall be provided with earth-leakage protection in the main supply circuit by

a) a double-pole RCD having a maximum nominal trip sensitivity of 30 mA and 100 ms maximum trip time located in accordance with 7.2.2, or
b) each receptacle located in the galley, toilet, machinery space or weather deck shall be protected by a GFCI (RCD) having a maximum sensitivity of 10 mA.

8.3 The GFCI (RCD) device shall have an internal circuit for manual testing of the trip function.

NOTE GFCI (RCD) double-pole receptacle (socket) devices may be installed as part of a convenient outlet installation, either in single-outlet applications or in multiple "feed through" installations, i.e. a series of receptacle (socket) outlets connected in parallel such that the first GFCI (RCD) protects everything in the circuit.

### 9 Appliances and equipment

Appliances and fixed a.c. electrical equipment installed on a craft shall have exposed conductive parts connected to the protective conductor, unless the appliance is of double-insulated construction.

Integral overcurrent protection shall be provided.

### 10 System wiring

10.1 Conductors shall have a minimum rating of 300/500 V. Flexible cords shall have a minimum rating of 300/300 V.

10.2 Conductors and flexible cords shall be of multistrand copper, and of sizes no smaller than those determined by reference to Table A.1.

NOTE A conductor used for equipment grounding is not considered to be a current-carrying conductor when making reference to Table A.1.

10.3 The insulation-temperature rating of conductors and flexible cords outside engine spaces shall be at least 60 °C.

10.4 Conductors shall be at least 1 mm² in area.

An exception may be made for conductors of minimum 0,75 mm² area which may be used as internal wiring in panel-boards.

8 © ISO 2000 – All rights reserved

10.5 Temperature ratings of conductor insulation in engine spaces shall be 70 °C minimum. The conductors shall be rated oil-resistant, or shall be protected by an insulating conduit or sleeving, and shall be derated in allowable current-carrying capacity in accordance with annex A.

10.6 The protective conductor shall not have a cross-sectional area less than that of the live conductor in the supply circuit.

10.7 Live, neutral and protective conductors of the a.c. system shall be identified. Identification may be made by the insulation colour, by numbering or other means, if a wiring diagram for the system indicating the means of identification is supplied with the craft.

Insulation colours used, in conformance with IEC 60446:

| live conductors: black or brown;
| neutral conductors: white or light blue;
| protective conductors: green or green with a yellow stripe (see 4.1).
NOTE | A colour stripe may be added to live and neutral conductor insulation for identification in the system.

Yellow, green or green with a yellow stripe insulation colour shall not be used for live or neutral conductors of the a.c. system.

### 11 Installation

11.1 Conductor connections shall be in locations protected from the weather or in IP 55 enclosures, in accordance with IEC 60529, as a minimum. Connections above deck exposed to intermittent immersion shall be in IP 67 enclosures, in accordance with IEC 60529, as a minimum.

11.2 Conductors shall be supported throughout their length in conduits, cable trunking or trays, or by individual supports at maximum intervals of 450 mm.

11.3 An a.c. circuit shall not be contained in the same wiring system as a d.c. circuit, unless one of the following methods of separation is used.

a) For a multicore cable or cord, the cores of the a.c. circuit are separated from the cores of the d.c. circuit by an earthed metal screen of equivalent current-carrying capacity to that of the largest core of the a.c. circuit.
b) The cables are insulated for their system voltage and installed in a separate compartment of a cable ducting or trunking system.
c) The cables are installed on a tray or ladder where physical separation is provided by a partition.
d) A separate conduit, sheathing or trunking system is used.
e) The a.c and d.c. conductors are fixed directly to a surface and separated by at least 100 mm.

11.4 Current-carrying conductors of the a.c. system shall be routed above forseeable levels of bilge water and in other areas where water may accumulate, or at least 25 mm above the water level at which the automatic bilge-pump switch activates.

If conductors must be routed in the bilge area, the wiring and connections shall be in IP 67 enclosures, in accordance with IEC 60529, such as continuous conduit, as a minimum, and there shall be no connections below the forseeable water level.

© ISO 2000 – All rights reserved | 9

11.5 Metals used for terminal studs, nuts and washers shall be corrosion-resistant and galvanically compatible with the conductor and terminal. Aluminium and unplated steel shall not be used for studs, nuts or washers in electrical circuits.

11.6 Solderless crimp-on terminals and connectors shall be attached with the type of crimping tool designed for the termination used and for producing a connection meeting the requirements of 11.13.

11.7 All conductors shall have suitable terminals installed, i.e. no bare wires attached to stud or screw connections.

11.8 Screw-clamp or screwless terminals shall conform to IEC 60947-7-1. Other terminals shall be of the ring or captive-spade type, not dependent on screw or nut tightness alone for retention on the screw or stud. Captive-spade terminals shall be of the self-locking type.

An exception is that friction-type connectors may be used in circuits not exceeding 20 A if the connection does not separate when subjected to a force of 20 N.

11.9 Twist-on connectors (wire nuts) shall not be used.

11.10 Exposed shanks of terminals shall be protected against accidental shorting by the use of insulating barriers or sleeves, except those in the protective conductor system.

11.11 Conductors shall be routed away from exhaust pipes and other heat sources which can damage the insulation. The minimum clearance is 50 mm from water-cooled exhaust components, and 250 mm from dry exhaust components, unless an equivalent thermal barrier is provided.

11.12 Conductors which may be exposed to physical damage shall be protected by sheaths, conduits or other equivalent means. Conductors passing through bulkheads or structural members shall be protected against insulation damage by chafing.

11.13 Each conductor-to-connector and conductor-to-terminal connection shall be capable of withstanding a tensile force equal to at least the value shown in Table 1 for the smallest conductor in the connection for 1 min, without separating.

Table 1 — Tensile values for connectors

Conductor size mm² | Tensile force N | Conductor size mm² | Tensile force N | Conductor size mm² | Tensile force N
0,75 1 1,5 2,5 4 | 40 60 130 150 170 | 6 10 16 25 35 | 200 220 260 310 350 | 50 70 95 120 150 | 400 440 550 660 770

11.14 No more than four conductors shall be secured to one terminal stud.

### 12 Panel-boards (switchboards)

12.1 An a.c. system panel-board with a lamp indicating the system on/off function shall be installed.

12.2 A system voltmeter shall be installed on the panel-board if the system is designed to supply motor circuits or if an on-board generator is installed.

10 © ISO 2000 – All rights reserved

12.3 Panel-boards shall be permanently marked with the system voltage.

EXAMPLE 230 V a.c. or 230 V, 50 Hz.

12.4 The front side of panel-boards, i.e. the switch and circuit-breaker operating face, shall be readily accessible, and the rear side, i.e. the terminal and connection side, accessible.

12.5 Connections and components on panel-boards shall be in locations protected from the weather, in conformity with IEC 60529:

| IP 67 as a minimum, if exposed to short-term immersion;
| IP 56 as a minimum, if exposed to splashing water;
| IP 20 as a minimum, if located in protected locations inside the craft.

12.6 Craft equipped with both d.c. and a.c. electrical systems shall have their distribution from either separate panel-boards or from a common one with a partition or other positive means provided to separate clearly the a.c. and d.c. sections from each other, and be clearly identified. Wiring diagrams to identify circuits, components and conductors shall be included with the craft.

### 13 Receptacles/sockets

13.1 Receptacles/sockets and matching plugs used on a.c. systems shall not be interchangeable with those used in the d.c. system on the craft.

13.2 Receptacles/sockets installed in locations subject to rain, spray or splashing shall be able to be enclosed in IP 55 enclosures, in accordance with IEC 60529, as a minimum, when not in use. Receptacles mated with the appropriate plug shall also remain sealed, in accordance with IEC 60529.

13.3 Receptacles/sockets installed in areas subject to flooding or momentary submersion shall be in IP 56 enclosures, in accordance with IEC 60529, as a minimum, also meeting these requirements when in use with electrical plugs.

13.4 Receptacles/sockets shall be of the earthing type with a terminal provided for the protective conductor.

13.5 Receptacles/sockets provided for the galley area shall be located so that appliance cords may be plugged in without crossing above a galley stove or sink or across a traffic area.

13.6 Receptacles/sockets shall have a voltage rating in accordance with the voltage supplied by the power sources.

### 14 Power-source options

### 14.1 Power for the a.c. system shall be supplied by one of the following means:

a) single shore-power cable, power inlet, wiring and components with a capacity to supply the required design-system load;
b) multiple shore-power cables, power inlets, wiring and components with a capacity to supply the required design-system load;
c) inverter supplying a.c. power from the craft's d.c. system;
d) on-board a.c. generator(s) supplying the required system load;

© ISO 2000 – All rights reserved | 11
e) combination of shore-power cable(s) and on-board generator(s) used simultaneously if the craft's circuitry is arranged such that the load connected to each source is isolated from the other in accordance with 4.6.

14.2 The shore-power cable(s) capacity alone, or with on-board generator(s) capacity in addition, shall be at least as large as the required system load(s).

14.3 A.c. generators, where installed, shall be connected to the electrical distribution system as required in 4.6 or protected in accordance with 4.7.

14.4 The power-feeder conductor from the a.c. generator shall be sized to transmit at least the generator's maximum rated output and shall be protected at the generator with overcurrent protection devices with a rating such that 120 % of the generator nominal output is not exceeded.

An exception may be made for self-limiting (self-adjusting) generators whose maximum overload current does not exceed 120 % of its rated current output; these do not require additional external overcurrent protection.

12 © ISO 2000 – All rights reserved

## Annex A (normative)

## Conductor requirements

Table A.1 gives allowable continuous current ratings, in amperes, at different temperature ratings and the minimum number of strands for conductors. These values have been determined for an ambient temperature of 30 °C and apply to single conductors and stranding when no more than three conductors are bundled together.

For conductors in engine rooms (60 °C ambient) or when more than three conductors are bundled together, the maximum current rating in Table A.1 shall be derated by the factors listed below:

Temperature rating of conductor insulation: | Multiply maximum current from Table A.1 by:
70 °C
85 °C to 90 °C
105 °C
125 °C
200 °C

0,75
0,82
0,86
0,89
1
Number of conductors bundled: | Multiply maximum amperage from Table A.1 by:
4 to 6
7 to 24
25 or more

0,7
0,6
0,5

NOTE Derating reductions for temperature and bundling are cumulative.

Tableau A.1 — Cross-sectional area of conductor, allowable continuous current and stranding

Cross-sectional area | Maximum continuous current-carrying capacity, in amperes, for single conductors at insulation temperature ratings | Minimum number of strands
0,75 1 1,5 2,5 4 6 10 16 25 35 50 70 95 120 150 | 6 8 12 17 22 29 40 54 71 87 105 135 165 190 220 | 10 14 18 25 35 45 65 90 120 160 210 265 310 360 380 | 12 18 21 30 40 50 70 100 140 185 230 285 330 400 430 | 16 20 25 35 45 60 90 130 170 210 270 330 390 450 475 | 20 25 30 40 50 70 100 150 185 225 300 360 410 480 520 | 25 35 40 45 55 75 120 170 200 240 325 375 430 520 560 | 16 16 19 19 19 19 19 37 49 127 127 127 259 418 418 | — — 26 41 65 105 168 266 420 665 1 064 1 323 1 666 2 107 2 107
mm² | 60 °C | 70 °C | 85 C to 90 °C | 105 °C | 125 °C | 200 °C | Type A | Type B

Conductors with at least Type A stranding shall be used for general wiring of the craft. Conductors with Type B stranding shall be used for any wiring where frequent flexing is involved during use.
NOTE Conductor current ratings may be interpolated for cross-sectional areas between those shown above.

© ISO 2000 – All rights reserved | 13

## Annex B (normative)

## Instructions to be included with owner's manual (ISO10240)

If an alternating current electrical system is installed in a craft, the owner's manual shall include instructions for the operation and maintenance of the system, including a wiring diagram with conductor identification, and at least the following.

a) Do not modify the craft's electrical systems or relevant drawings. Installation, alterations and maintenance should be performed by a competent marine electrical technician. Inspect the system at least biennially.
b) Disconnect shore-power connections when the system is not in use.
c) Connect metallic housings or enclosures of installed electrical appliances to the protective conductor system in the craft (green or green with a yellow stripe conductor).
d) Use double insulated or grounded (earthed) electrical appliances.
e) If the reverse polarity indicator is activated, do not use the electrical system. Correct the polarity fault before activating the electrical system on the craft.²
f) WARNING — Do not allow the shore-power cable end to hang in the water. An electrical field can be caused which can cause injury or death to nearby swimmers.
g) WARNING — To minimize shock and fire hazards.
| Turn off craft's shore-power connection switch before connecting or disconnecting shore-power cable.
| Connect shore-power cable to craft’s inlet before connecting to shore-power source.³
| Disconnect shore-power cable at shore-power source first.
| If reverse polarity indicator is activated, disconnect cable immediately.⁴
| Close shore-power inlet cover tightly.

Do not alter shore-power cable connectors, use only compatible connectors.

2 | Required for polarized systems with polarity indicator.
3 | Not required for permanently connected shore-power cable installations.
4 | Required only if a reverse polarity indicator is required in the system.

14 © ISO 2000 – All rights reserved

## Annex C (informative)

## Recommended system tests

The following system tests should be performed upon completion of the a.c. installation.

| Residual current device (RCD) testing.
| Continuity test of circuits, particularly ring and protective circuits.
| Insulation resistance testing at 500 V d.c. for each circuit.
| Polarity test at distribution and at each outlet.

CAUTION — Some electronic equipment may be damaged by high d.c. voltages.

© ISO 2000 – All rights reserved | 15

## Annex D (informative)

## Related standards and brief description of their contents

[1] ISO 10088:—⁵
, Small craft — Permanently installed fuel systems and fixed fuel tanks.

Individual fuel tanks, 100 % pressure tested Non-metallic fuel tanks, fire tested
Fire-resistant flexible fuel hoses
Fire test for non-metallic fuel-system components Corrosion-resistant fuel-tank materials Galvanically compatible metallic parts Anti-siphon protection requirements
Double clamping of fuel-fill hoses
Electrically ground (earth) all metallic parts
100 % pressure test of entire fuel system
[2] ISO 8846:1990, Small craft — Electrical devices — Protection against ignition of surrounding flammable gases.

All components in petrol engines, petrol and LPG tank compartments to be ignition-protected to prevent open sparks. This applies to the entire engine, as well as all electrical contacts, commutators, brushes, collector rings, switches, relays, generators, fuses, distributors, engine-cranking motors, propulsion-trim motors, etc.

ISO 8846 further requires components to withstand any operating conditions of the device, including the maximum achievable overload up to 400 % of the rated current (circuit-breakers, switches and the like) and a stalled rotor condition for any motor with the circuit protected in an overcurrent protective device specified by the product manufacturer.

[3] ISO 9097:1991, Small craft — Electric fans.
[4] ISO 8849:1990, Small craft — Electrically operated bilge-pumps.

All components, if installed in a petrol engine, petrol or LPG tank compartment to be ignition-protected, have all wiring insulated, be suitable for marine environment, and not create a hazard when the motor is overloaded or stalled.

[5] ISO 10133:2000, Small craft — Electrical systems — Extra-low-voltage d.c. installations

All components fused
All conductors insulated
All electrical components installed in bilges or other compartments that may contain explosive gas are ignition protected
Installation requirements for batteries and cables
Requirements for ring or captive-spade terminals on conductor connectors

5 To be published. (Revision of ISO 10088:1992)

16 © ISO 2000 – All rights reserved

[6] ISO 10239:—⁶
, Small craft — Liquefied petroleum gas (LPG) systems.

System to withstand temperature extremes
Appliances approved and installed only in ventilated compartments, tanks and pressure regulators in lockers identified and vented with overboard drains
Meet specifications for fuel lines and their supports
Appliance well secured with flame-failure shutoff control device for each appliance.
Warning labels on appliances
Pressure test on installed system
Any electrical device in lockers, designated for fuel storage, ignition-protected
[7] ISO 9094–1:—⁶⁾, Small craft — Fire protection — Part 1: Craft with a hull length of up to and including 15 m.

ISO 9094–2:—⁶⁾, Small craft — Fire protection — Part 2: Craft with a hull length of more than 15 m and up to and including 24 m.

Specifications for exits and emergency exits
Material specifications in areas close to open flames
Self-extinguishing materials in engine compartment Ventilation and flue protection for water heater
Sealed combustion systems on unattended appliances
Specification for fuel tanks
Requirement for portable fire-extinguishers, for accessibility, protection, stowage and locker identification size Specification for number and types of fire-extinguishers
Specification for fixed fire-extinguishing system on some craft
Cylinder installation specification
Remote release for fixed systems
Fire-resistant distribution hoses and tubes
Specifications for discharge and control
Discharge and operating instructions
[8] ISO 11105:1997, Small craft — Ventilation of petrol engine and/or petrol tank compartments.

Ventilation amount based on compartment volume
Specification for compartment tightness
Natural and powered ventilation in engine compartments
Natural ventilation in certain fuel compartments
Ventilation openings on exterior of craft
Blower warning for craft operator
[9] ISO 10134:1993, Small craft — Electrical devices — Lightning protection.

Requirements for design, construction and installation of lightning-protection equipment, if fitted on small craft

[10] IEC 60364-7-709:1994, Electrical installations of buildings — Part 7: Requirements for special installations or locations — Section 709: Marinas and pleasure craft.

A.c. systems for marinas and connection to the craft

6 To be published.

ICS 47.080
Price based on 16 pages

© ISO 2000 – All rights reserved

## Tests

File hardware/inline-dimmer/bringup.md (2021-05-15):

# Bringup notest LED Driver

## REV 1

* 68 nF for 180 Hz PWM frequency (with 100 k potentiometer)
* Approx 30 uA off current when switch open (off)
* Approx 400 uA (higher than expected?) when switch closed and battery in undervoltage (set to 10 V).
* Solid on/off operation at 13.2 volt and above. There is a band where PWM operation seems unreliable but still not clear why (Dampening decoupling needed?)?

- [ ] Check what the calculated on/off voltages should be
- [ ] Try with long LED strip to verify stability

If the PWM circuit gives to much trouble just convert to on/off control only by removing and installing jumper instead of mosfet.

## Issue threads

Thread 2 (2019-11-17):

Fuses on PCB

oskarjohansson, 2019-11-17:
These connection wont have any fuse to them, so would be good with a fuse between mosfet and output. All 6A to not exceed the connectors rating.

oskarjohansson, 2019-11-17:
- Added 20x5mm fuses.
- Quite small, but cheap.
- Only 6A.

oskarjohansson, 2020-09-18:
In the power-distribution hardware folder is a nice 4 fuse board with capability of about 150 W per channel.

Closed 2020-09-18.

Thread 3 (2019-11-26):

Find hall current meter.

oskarjohansson, 2019-11-26:
To measure current with instead of a current shunt.

oskarjohansson, 2019-11-26:
Like
https://www.digikey.se/product-detail/sv/lem-usa-inc/HAIS-50-P/398-1029-ND/1026520

oskarjohansson, 2019-11-26:
Or
https://www.digikey.se/product-detail/sv/lem-usa-inc/HTB-50-TP/398-1075-ND/1701118

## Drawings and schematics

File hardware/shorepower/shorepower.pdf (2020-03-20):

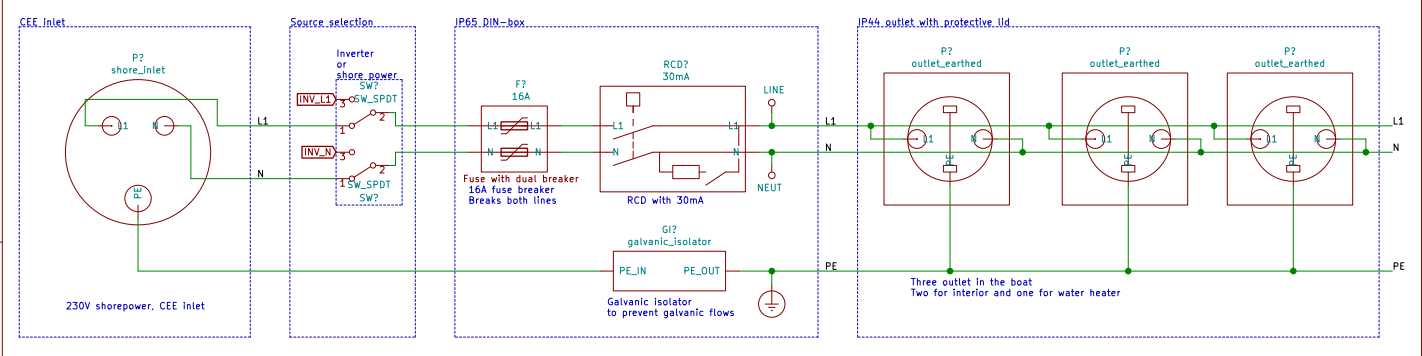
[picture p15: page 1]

Inverter or shore power Source selection

16A fuse breaker Breaks both lines

File: shorepower.sch Sheet: /
Id: 1/1 Title:

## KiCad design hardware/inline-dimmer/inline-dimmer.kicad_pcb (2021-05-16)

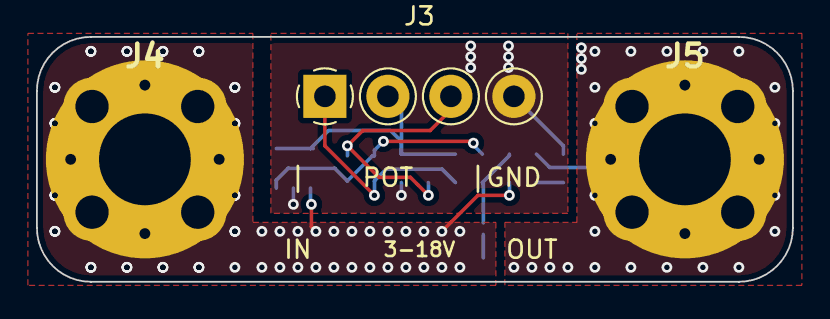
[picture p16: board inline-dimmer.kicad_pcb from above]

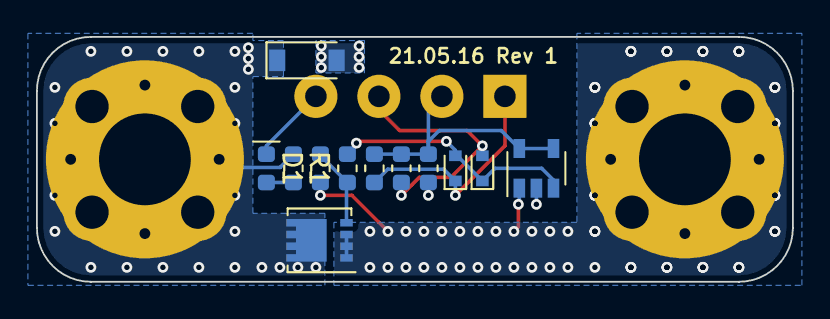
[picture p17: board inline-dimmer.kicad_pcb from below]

Board: 2 copper layers, 42.0 x 13.6 mm, 17 parts (12 on the bottom side), 10 nets.

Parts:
C3: 2.2uF 16V; C_0603_1608Metric
D1: LED; LED_0603_1608Metric
D2, D3: RB751S40T5G; D_SOD-523
D5: D_Schottky; D_SOD-123
J1, J2: Conn_01x01; MountingHole_5.5mm_Pad_Via
J3: 1984633; TerminalBlock_4Ucon_1x04_P3.50mm_Horizontal
J4, J5: 74651175R; M5_74651175R_Solder
Q2: DMP3013SFV; Diodes_PowerDI3333-8
R1: 2k; R_0603_1608Metric
R7, R8: R; R_0603_1608Metric
R9: 100k; R_0603_1608Metric
R10: 1k; R_0603_1608Metric
U1: MIC1555YM5-TR; SOT-23-5

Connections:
+12V: J1.1, J4.1, R9.2, U1.1
/GATE: R9.1, R10.1
/LED_OUT: D5.1, J2.1, J5.1, R1.1
/PWM: D2.2, D3.1, R10.2, U1.3
/TRG_THR: C3.1, J3.2, R7.2, R8.2, U1.4, U1.5
GND: C3.2, D1.1, D5.2, J3.4, U1.2
unnamed: D1.2, R1.2
unnamed: D2.1, J3.1, R7.1
unnamed: D3.2, J3.3, R8.1
unnamed: Q2.1, Q2.2, Q2.3

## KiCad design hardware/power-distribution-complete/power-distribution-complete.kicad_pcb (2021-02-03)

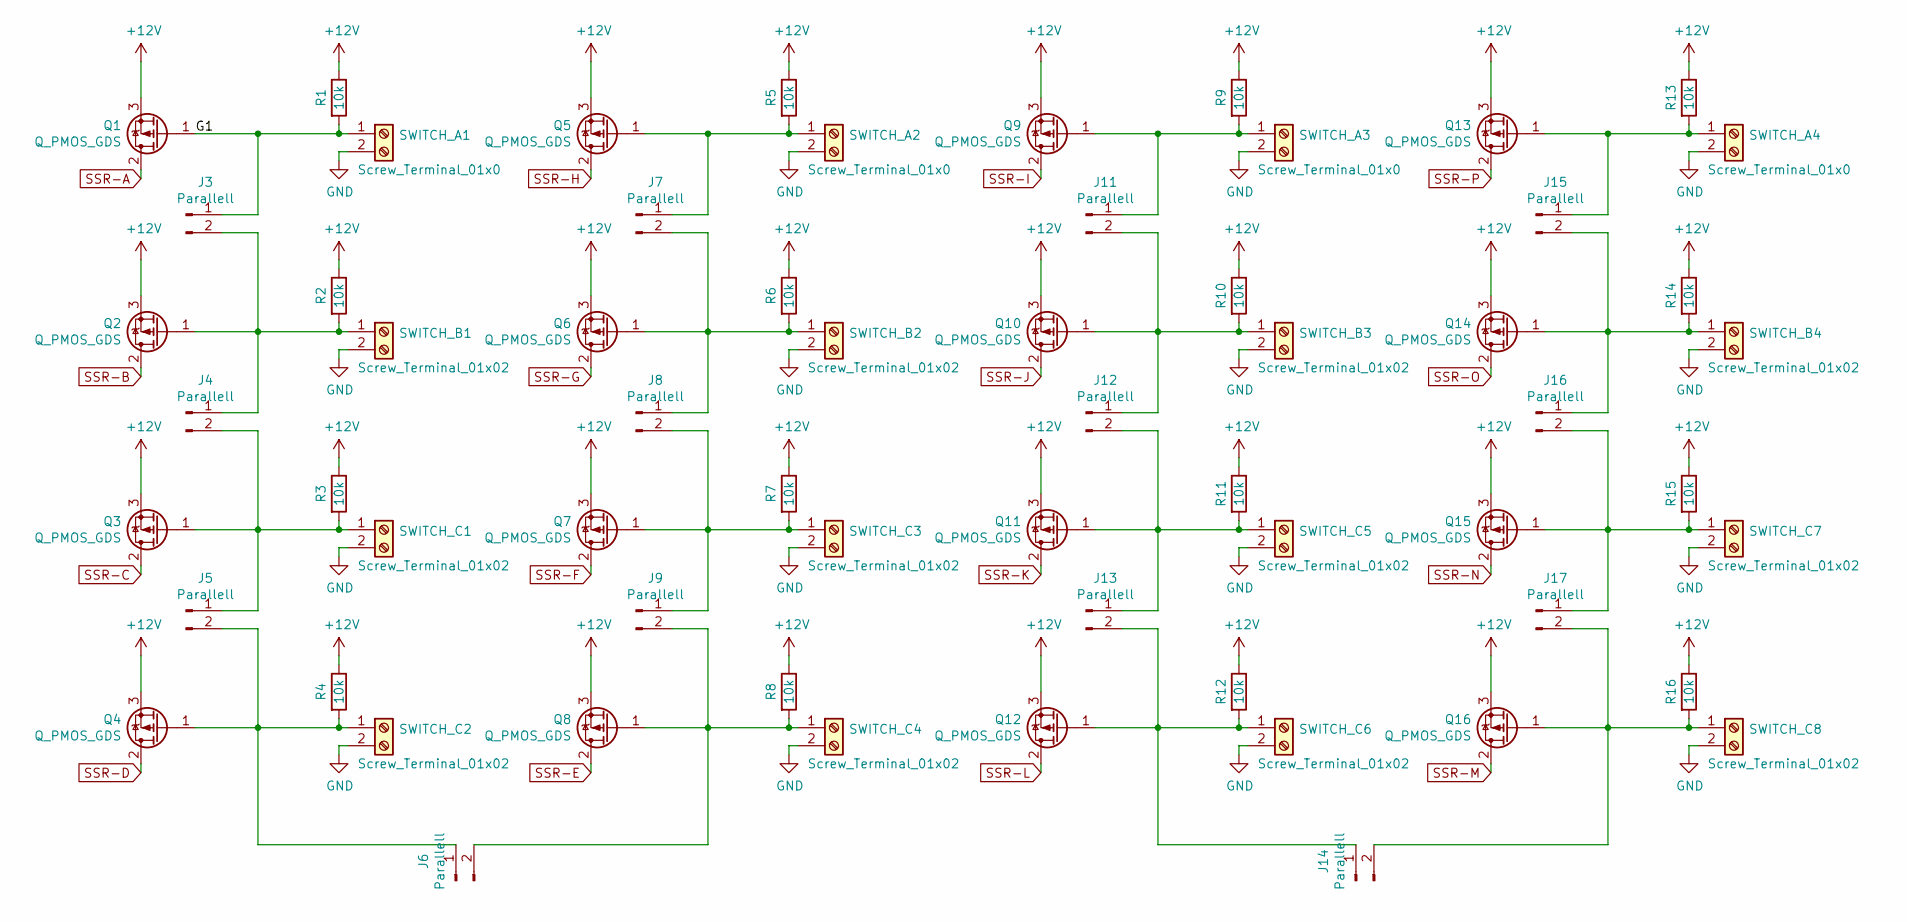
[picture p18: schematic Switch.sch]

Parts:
J3, J4, J5, J6, J7, J8, J9, J11, J12, J13, J14, J15, J16, J17: Parallell; PinHeader_1x02_P2.54mm_Vertical
Q1, Q2, Q3, Q4, Q5, Q6, Q7, Q8, Q9, Q10, Q11, Q12, Q13, Q14, Q15, Q16: Q_PMOS_GDS; TO-252-2-ThermalVias
R1, R2, R3, R4, R5, R6, R7, R8, R9, R10, R11, R12, R13, R14, R15, R16: 10k; R_0603_1608Metric_Pad1.05x0.95mm_HandSolder
SWITCH_A1, SWITCH_A2, SWITCH_A3, SWITCH_A4: Screw_Terminal_01x0; TerminalBlock_02_P5.00mm
SWITCH_B1, SWITCH_B2, SWITCH_B3, SWITCH_B4: Screw_Terminal_01x02; TerminalBlock_02_P5.00mm
SWITCH_C1, SWITCH_C2, SWITCH_C3, SWITCH_C4, SWITCH_C5, SWITCH_C6, SWITCH_C7, SWITCH_C8: Screw_Terminal_01x02; TerminalBlock_02_P5.00mm

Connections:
+12V: Q1.3 (S), Q2.3 (S), Q3.3 (S), Q4.3 (S), Q5.3 (S), Q6.3 (S), Q7.3 (S), Q8.3 (S), Q9.3 (S), Q10.3 (S), Q11.3 (S), Q12.3 (S), Q13.3 (S), Q14.3 (S), Q15.3 (S), Q16.3 (S), R1.1, R2.1, R3.1, R4.1, R5.1, R6.1, R7.1, R8.1, R9.1, R10.1, R11.1, R12.1, R13.1, R14.1, R15.1, R16.1; also elsewhere on the board
/Switch/G1: J3.1, Q1.1 (G), R1.2, SWITCH_A1.1
GND: SWITCH_A1.2, SWITCH_A2.2, SWITCH_A3.2, SWITCH_A4.2, SWITCH_B1.2, SWITCH_B2.2, SWITCH_B3.2, SWITCH_B4.2, SWITCH_C1.2, SWITCH_C2.2, SWITCH_C3.2, SWITCH_C4.2, SWITCH_C5.2, SWITCH_C6.2, SWITCH_C7.2, SWITCH_C8.2; also elsewhere on the board
unnamed: J3.2, J4.1, Q2.1 (G), R2.2, SWITCH_B1.1
unnamed: J4.2, J5.1, Q3.1 (G), R3.2, SWITCH_C1.1
unnamed: J5.2, J6.1, Q4.1 (G), R4.2, SWITCH_C2.1
unnamed: J6.2, J9.2, Q8.1 (G), R8.2, SWITCH_C4.1
unnamed: J7.1, Q5.1 (G), R5.2, SWITCH_A2.1
unnamed: J7.2, J8.1, Q6.1 (G), R6.2, SWITCH_B2.1
unnamed: J8.2, J9.1, Q7.1 (G), R7.2, SWITCH_C3.1
unnamed: J11.1, Q9.1 (G), R9.2, SWITCH_A3.1
unnamed: J11.2, J12.1, Q10.1 (G), R10.2, SWITCH_B3.1
unnamed: J12.2, J13.1, Q11.1 (G), R11.2, SWITCH_C5.1
unnamed: J13.2, J14.1, Q12.1 (G), R12.2, SWITCH_C6.1
unnamed: J14.2, J17.2, Q16.1 (G), R16.2, SWITCH_C8.1
unnamed: J15.1, Q13.1 (G), R13.2, SWITCH_A4.1
unnamed: J15.2, J16.1, Q14.1 (G), R14.2, SWITCH_B4.1
unnamed: J16.2, J17.1, Q15.1 (G), R15.2, SWITCH_C7.1
SSR-A: Q1.2 (D); also elsewhere on the board
SSR-B: Q2.2 (D); also elsewhere on the board
SSR-C: Q3.2 (D); also elsewhere on the board
SSR-D: Q4.2 (D); also elsewhere on the board
SSR-E: Q8.2 (D); also elsewhere on the board
SSR-F: Q7.2 (D); also elsewhere on the board
SSR-G: Q6.2 (D); also elsewhere on the board
SSR-H: Q5.2 (D); also elsewhere on the board
SSR-I: Q9.2 (D); also elsewhere on the board
SSR-J: Q10.2 (D); also elsewhere on the board
SSR-K: Q11.2 (D); also elsewhere on the board
SSR-L: Q12.2 (D); also elsewhere on the board
SSR-M: Q16.2 (D); also elsewhere on the board
SSR-N: Q15.2 (D); also elsewhere on the board
SSR-O: Q14.2 (D); also elsewhere on the board
SSR-P: Q13.2 (D); also elsewhere on the board

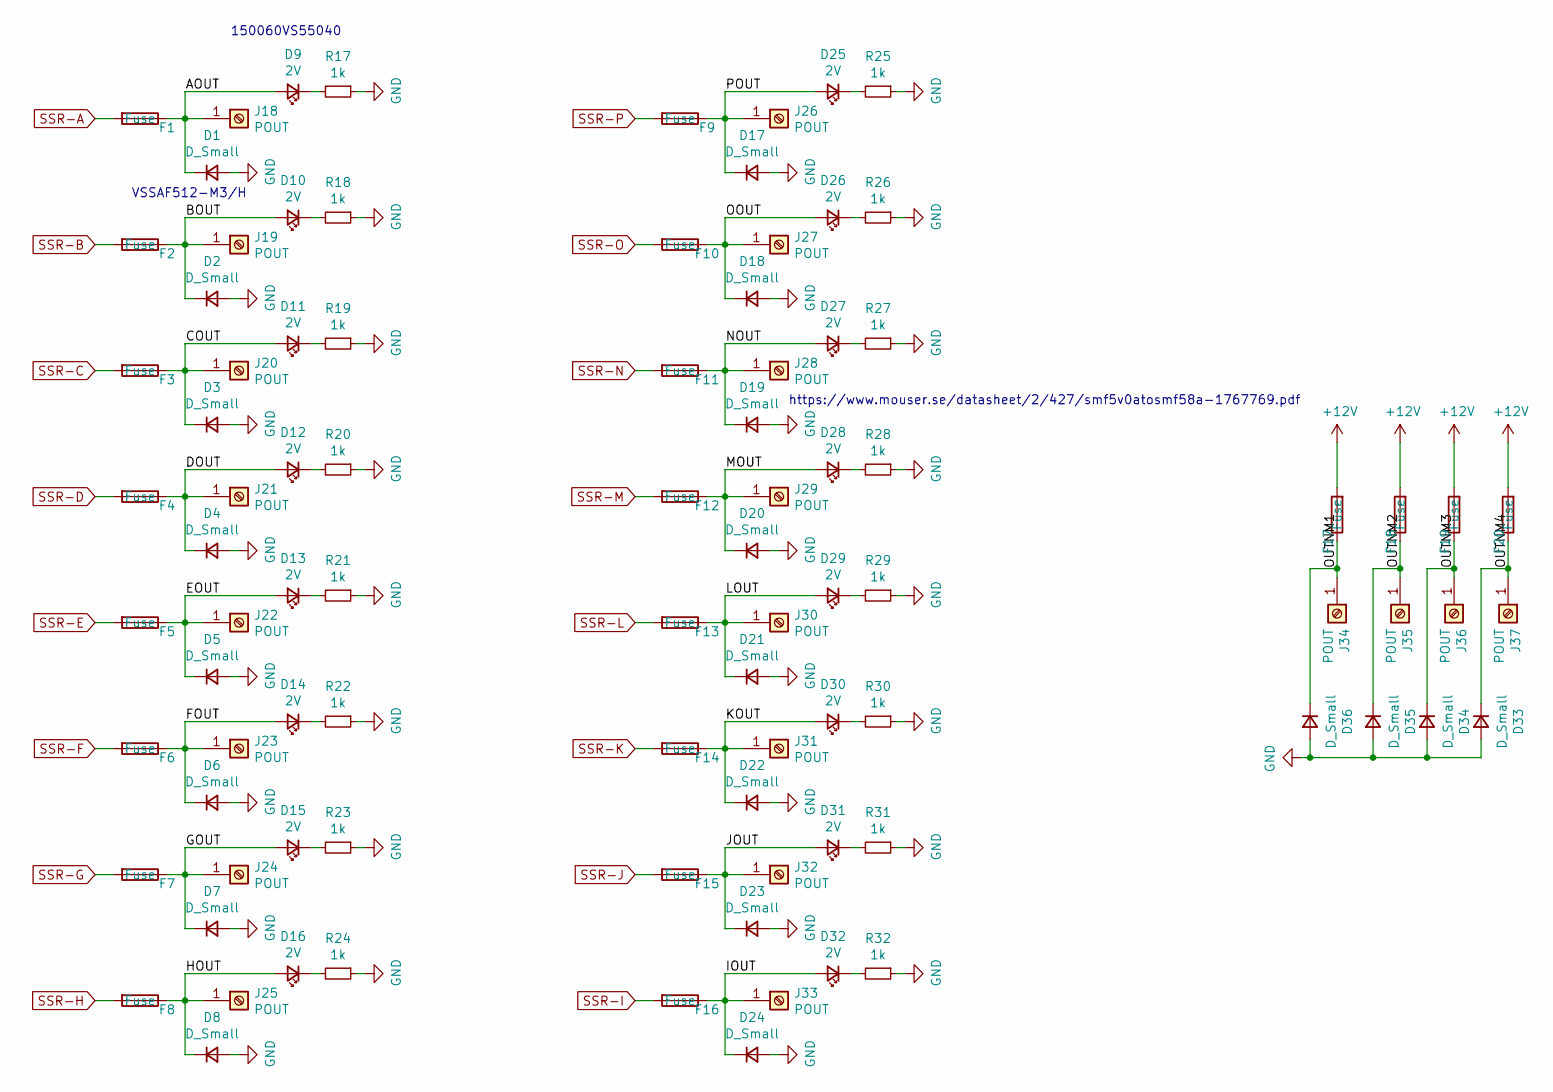
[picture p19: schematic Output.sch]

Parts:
D1, D2, D3, D4, D5, D6, D7, D8, D17, D18, D19, D20, D21, D22, D23, D24, D33, D34, D35, D36: D_Small; SMF-DO-219AB
D9, D10, D11, D12, D13, D14, D15, D16, D25, D26, D27, D28, D29, D30, D31, D32: 2V; LED_0603_1608Metric
F1, F2, F3, F4, F5, F6, F7, F8, F9, F10, F11, F12, F13, F14, F15, F16, F17, F18, F19, F20: Fuse; ATO_Fuseholder_3522-2
J18, J19, J20, J21, J22, J23, J24, J25, J26, J27, J28, J29, J30, J31, J32, J33, J34, J35, J36, J37: POUT; M5_7461383
R17, R18, R19, R20, R21, R22, R23, R24, R25, R26, R27, R28, R29, R30, R31, R32: 1k; R_0603_1608Metric

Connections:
+12V: F17.2, F18.2, F19.2, F20.2; also elsewhere on the board
/Output/AOUT: D1.1 (K), D9.2 (A), F1.1, J18.1
/Output/BOUT: D2.1 (K), D10.2 (A), F2.1, J19.1
/Output/COUT: D3.1 (K), D11.2 (A), F3.1, J20.1
/Output/DOUT: D4.1 (K), D12.2 (A), F4.1, J21.1
/Output/EOUT: D5.1 (K), D13.2 (A), F5.1, J22.1
/Output/FOUT: D6.1 (K), D14.2 (A), F6.1, J23.1
/Output/GOUT: D7.1 (K), D15.2 (A), F7.1, J24.1
/Output/HOUT: D8.1 (K), D16.2 (A), F8.1, J25.1
/Output/IOUT: D24.1 (K), D32.2 (A), F16.1, J33.1
/Output/JOUT: D23.1 (K), D31.2 (A), F15.1, J32.1
/Output/KOUT: D22.1 (K), D30.2 (A), F14.1, J31.1
/Output/LOUT: D21.1 (K), D29.2 (A), F13.1, J30.1
/Output/MOUT: D20.1 (K), D28.2 (A), F12.1, J29.1
/Output/NOUT: D19.1 (K), D27.2 (A), F11.1, J28.1
/Output/OOUT: D18.1 (K), D26.2 (A), F10.1, J27.1
/Output/OUTNM1: D36.1 (K), F17.1, J34.1
/Output/OUTNM2: D35.1 (K), F18.1, J35.1
/Output/OUTNM3: D34.1 (K), F19.1, J36.1
/Output/OUTNM4: D33.1 (K), F20.1, J37.1
/Output/POUT: D17.1 (K), D25.2 (A), F9.1, J26.1
GND: D1.2 (A), D2.2 (A), D3.2 (A), D4.2 (A), D5.2 (A), D6.2 (A), D7.2 (A), D8.2 (A), D17.2 (A), D18.2 (A), D19.2 (A), D20.2 (A), D21.2 (A), D22.2 (A), D23.2 (A), D24.2 (A), D33.2 (A), D34.2 (A), D35.2 (A), D36.2 (A), R17.1, R18.1, R19.1, R20.1, R21.1, R22.1, R23.1, R24.1, R25.1, R26.1, R27.1, R28.1, R29.1, R30.1, R31.1, R32.1; also elsewhere on the board
unnamed: D9.1 (K), R17.2
unnamed: D10.1 (K), R18.2
unnamed: D11.1 (K), R19.2
unnamed: D12.1 (K), R20.2
unnamed: D13.1 (K), R21.2
unnamed: D14.1 (K), R22.2
unnamed: D15.1 (K), R23.2
unnamed: D16.1 (K), R24.2
unnamed: D25.1 (K), R25.2
unnamed: D26.1 (K), R26.2
unnamed: D27.1 (K), R27.2
unnamed: D28.1 (K), R28.2
unnamed: D29.1 (K), R29.2
unnamed: D30.1 (K), R30.2
unnamed: D31.1 (K), R31.2
unnamed: D32.1 (K), R32.2
SSR-A: F1.2; also elsewhere on the board
SSR-B: F2.2; also elsewhere on the board
SSR-C: F3.2; also elsewhere on the board
SSR-D: F4.2; also elsewhere on the board
SSR-E: F5.2; also elsewhere on the board
SSR-F: F6.2; also elsewhere on the board
SSR-G: F7.2; also elsewhere on the board
SSR-H: F8.2; also elsewhere on the board
SSR-I: F16.2; also elsewhere on the board
SSR-J: F15.2; also elsewhere on the board
SSR-K: F14.2; also elsewhere on the board
SSR-L: F13.2; also elsewhere on the board
SSR-M: F12.2; also elsewhere on the board
SSR-N: F11.2; also elsewhere on the board
SSR-O: F10.2; also elsewhere on the board
SSR-P: F9.2; also elsewhere on the board

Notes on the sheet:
VSSAF512-M3/H
150060VS55040
https://www.mouser.se/datasheet/2/427/smf5v0atosmf58a-1767769.pdf

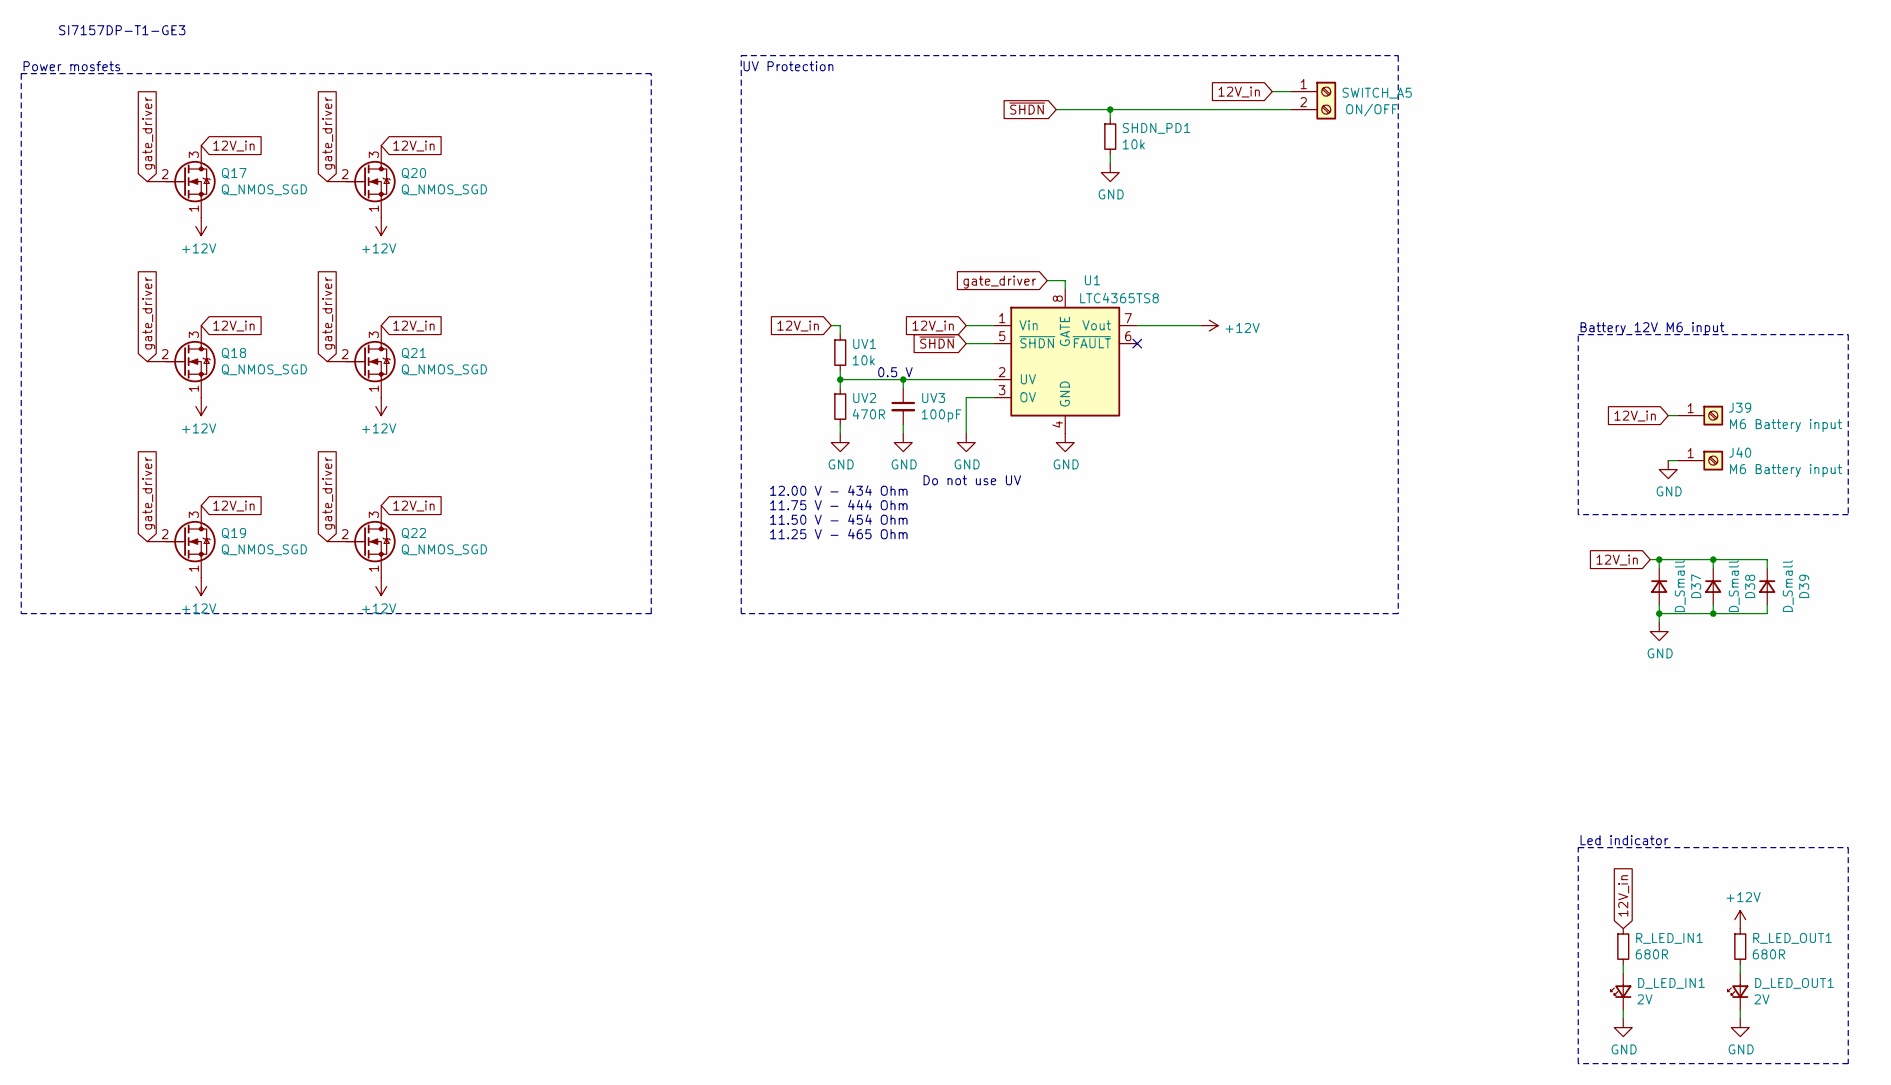
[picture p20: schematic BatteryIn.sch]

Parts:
D37, D38, D39: D_Small; SMF-DO-219AB
D_LED_IN1: 2V; LED_0603_1608Metric
D_LED_OUT1: 2V; LED_0603_1608Metric
J39, J40: M6 Battery input; M6_7461098
Q17, Q18, Q19, Q20, Q21, Q22: Q_NMOS_SGD; SQJA72EPT1_GE3
R_LED_IN1: 680R; R_0603_1608Metric
R_LED_OUT1: 680R; R_0603_1608Metric
SHDN_PD1: 10k; R_0603_1608Metric
SWITCH_A5: ON/OFF; TerminalBlock_02_P5.00mm
U1: LTC4365TS8; SOT-23-8
UV1: 10k; R_0603_1608Metric
UV2: 470R; R_0603_1608Metric
UV3: 100pF; C_0603_1608Metric

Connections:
12V_in: D37.1 (K), D38.1 (K), D39.1 (K), J39.1, Q17.3 (D), Q18.3 (D), Q19.3 (D), Q20.3 (D), Q21.3 (D), Q22.3 (D), R_LED_IN1.1, SWITCH_A5.1, U1.1 (Vin), UV1.1
+12V: Q17.1 (S), Q18.1 (S), Q19.1 (S), Q20.1 (S), Q21.1 (S), Q22.1 (S), R_LED_OUT1.1, U1.7 (Vout); also elsewhere on the board
GND: D37.2 (A), D38.2 (A), D39.2 (A), D_LED_IN1.1 (K), D_LED_OUT1.1 (K), J40.1, SHDN_PD1.2, U1.3 (OV), U1.4 (GND), UV2.2, UV3.2; also elsewhere on the board
unnamed: D_LED_IN1.2 (A), R_LED_IN1.2
unnamed: D_LED_OUT1.2 (A), R_LED_OUT1.2
unnamed: U1.2 (UV), UV1.2, UV2.1, UV3.1
gate_driver: Q17.2 (G), Q18.2 (G), Q19.2 (G), Q20.2 (G), Q21.2 (G), Q22.2 (G), U1.8 (GATE)
~SHDN: SHDN_PD1.1, SWITCH_A5.2, U1.5 (~SHDN)

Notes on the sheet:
Power mosfets
Battery 12V M6 input
UV Protection
Led indicator
SI7157DP-T1-GE3
0.5 V
Do not use UV
12.00 V - 434 Ohm 11.75 V - 444 Ohm 11.50 V - 454 Ohm 11.25 V - 465 Ohm

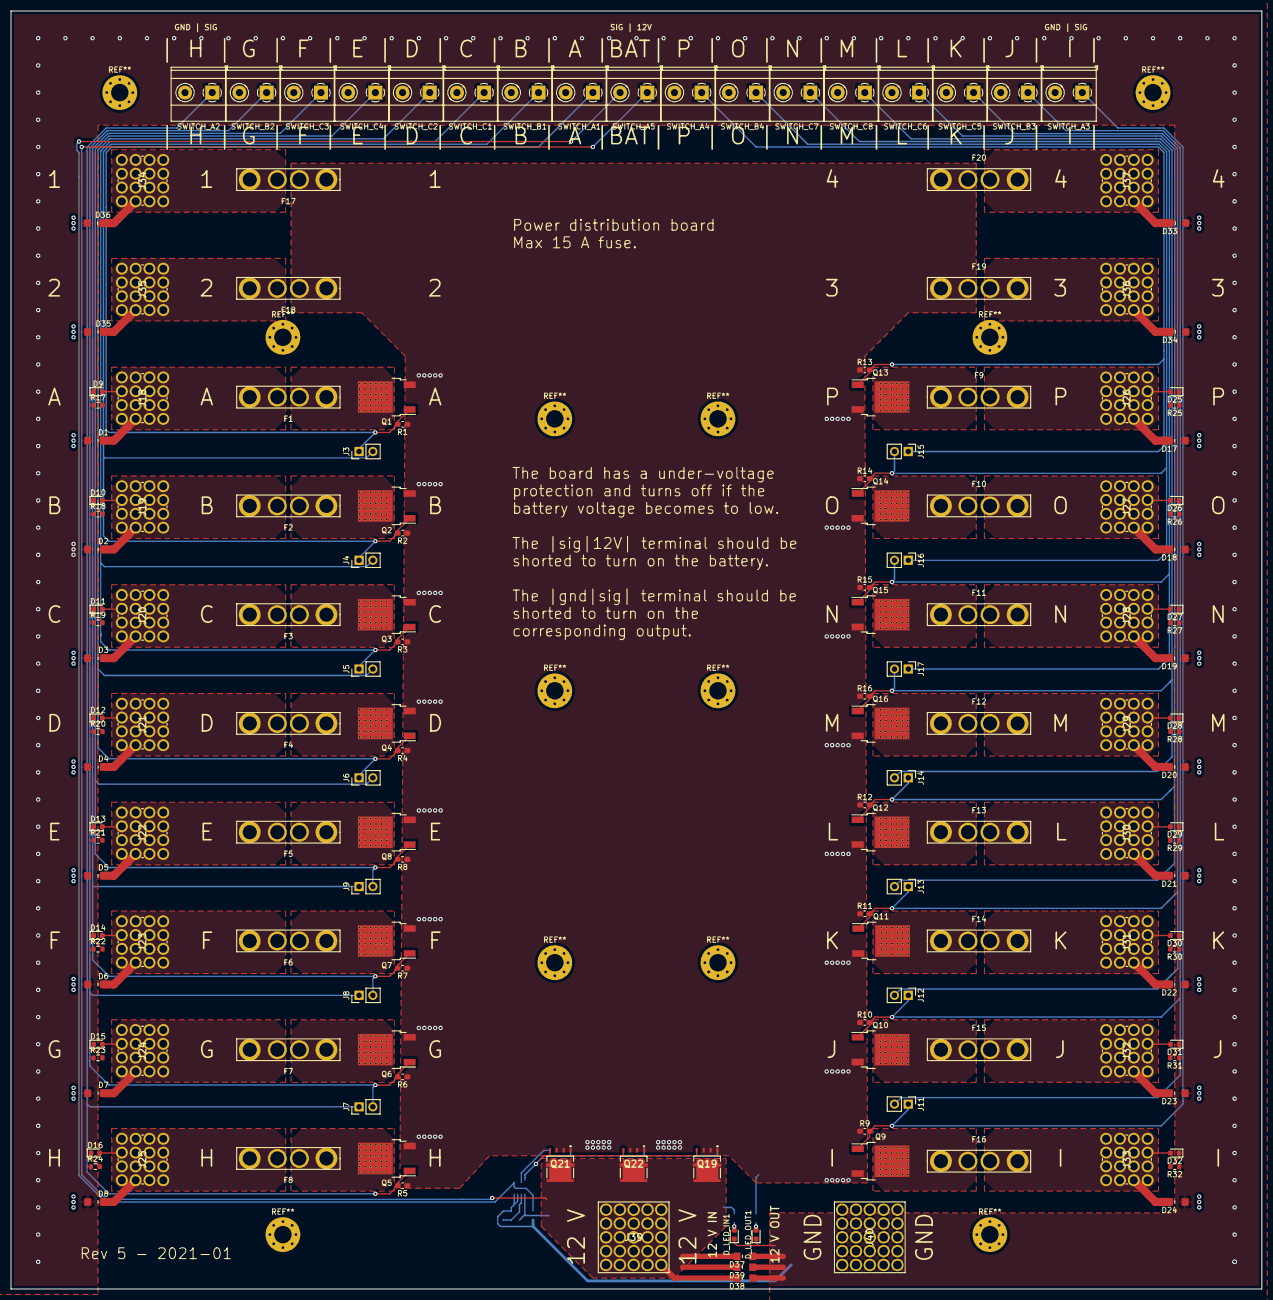
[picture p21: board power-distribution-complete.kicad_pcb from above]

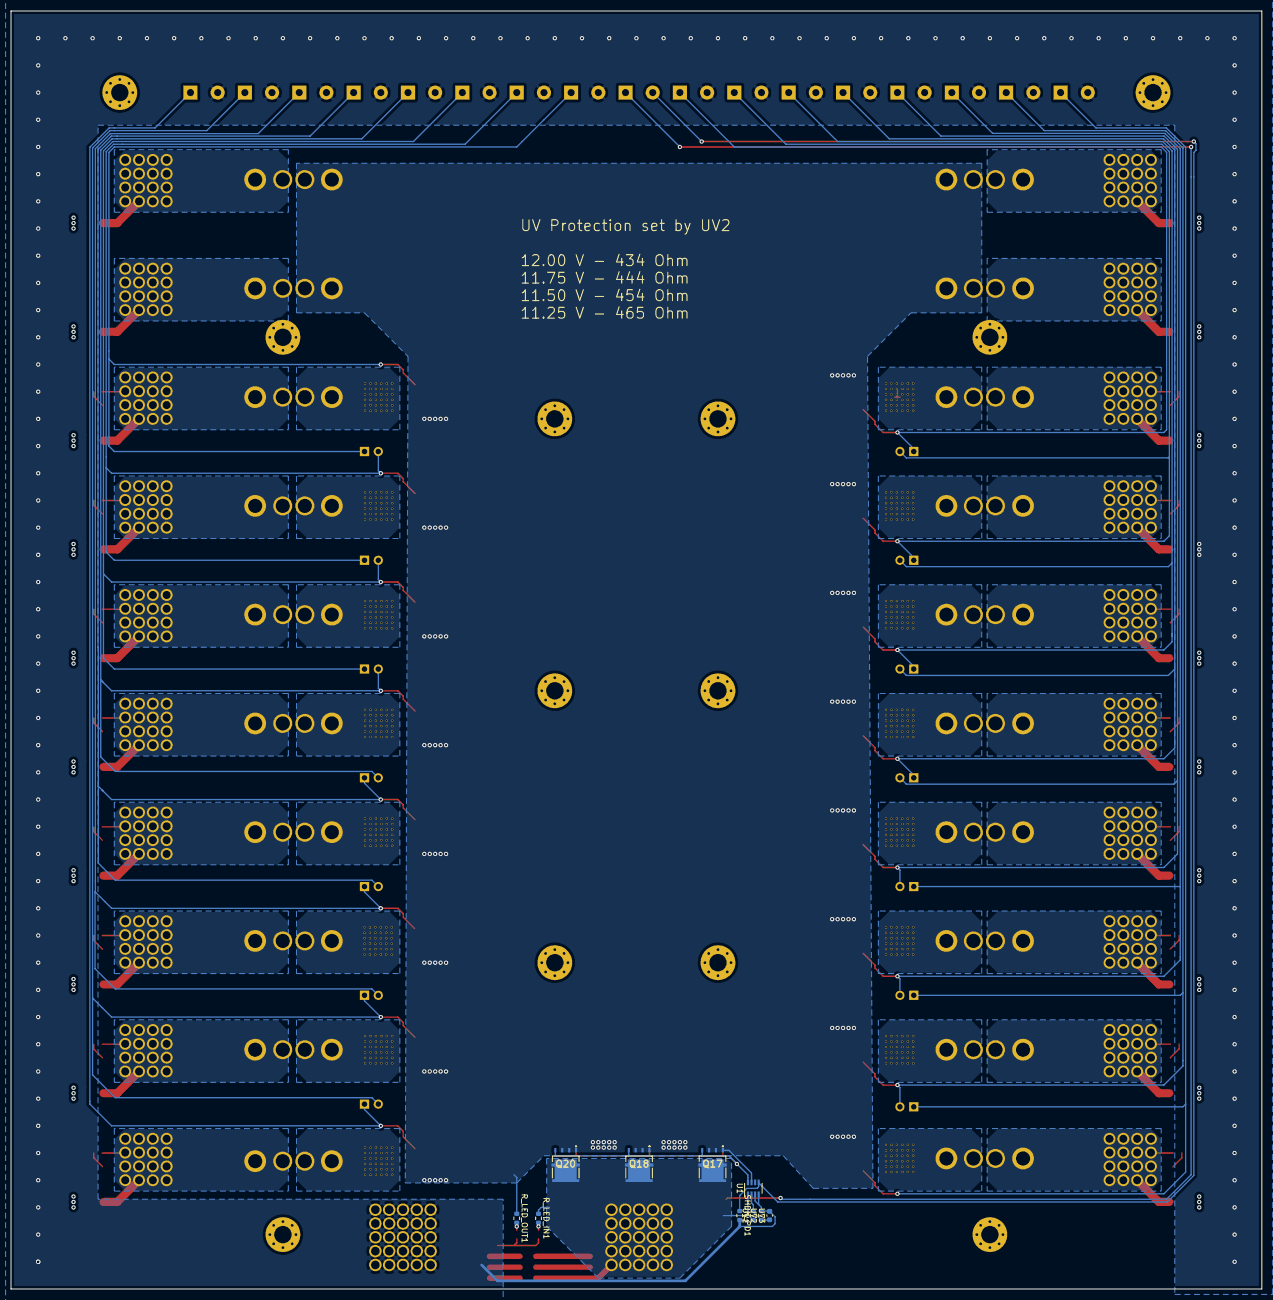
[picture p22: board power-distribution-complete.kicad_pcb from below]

Board: 2 copper layers, 230.0 x 235.0 mm, 175 parts (10 on the bottom side), 76 nets.

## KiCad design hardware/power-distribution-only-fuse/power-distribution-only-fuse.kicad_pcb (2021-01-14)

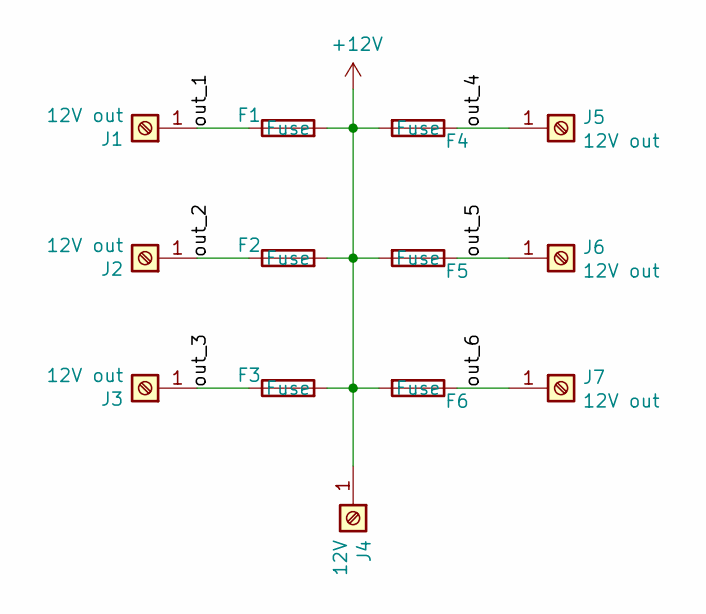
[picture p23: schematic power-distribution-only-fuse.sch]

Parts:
F1, F2, F3, F4, F5, F6: Fuse; ATO_Fuseholder_3522-2
J1, J2, J3, J5, J6, J7: 12V out; M5_7461383
J4: 12V; M6_7461098

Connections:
+12V: F1.2, F2.2, F3.2, F4.2, F5.2, F6.2, J4.1
/out_1: F1.1, J1.1
/out_2: F2.1, J2.1
/out_3: F3.1, J3.1
/out_4: F4.1, J5.1
/out_5: F5.1, J6.1
/out_6: F6.1, J7.1

Board: 2 copper layers, 13 parts (0 on the bottom side), 7 nets, no tracks yet.

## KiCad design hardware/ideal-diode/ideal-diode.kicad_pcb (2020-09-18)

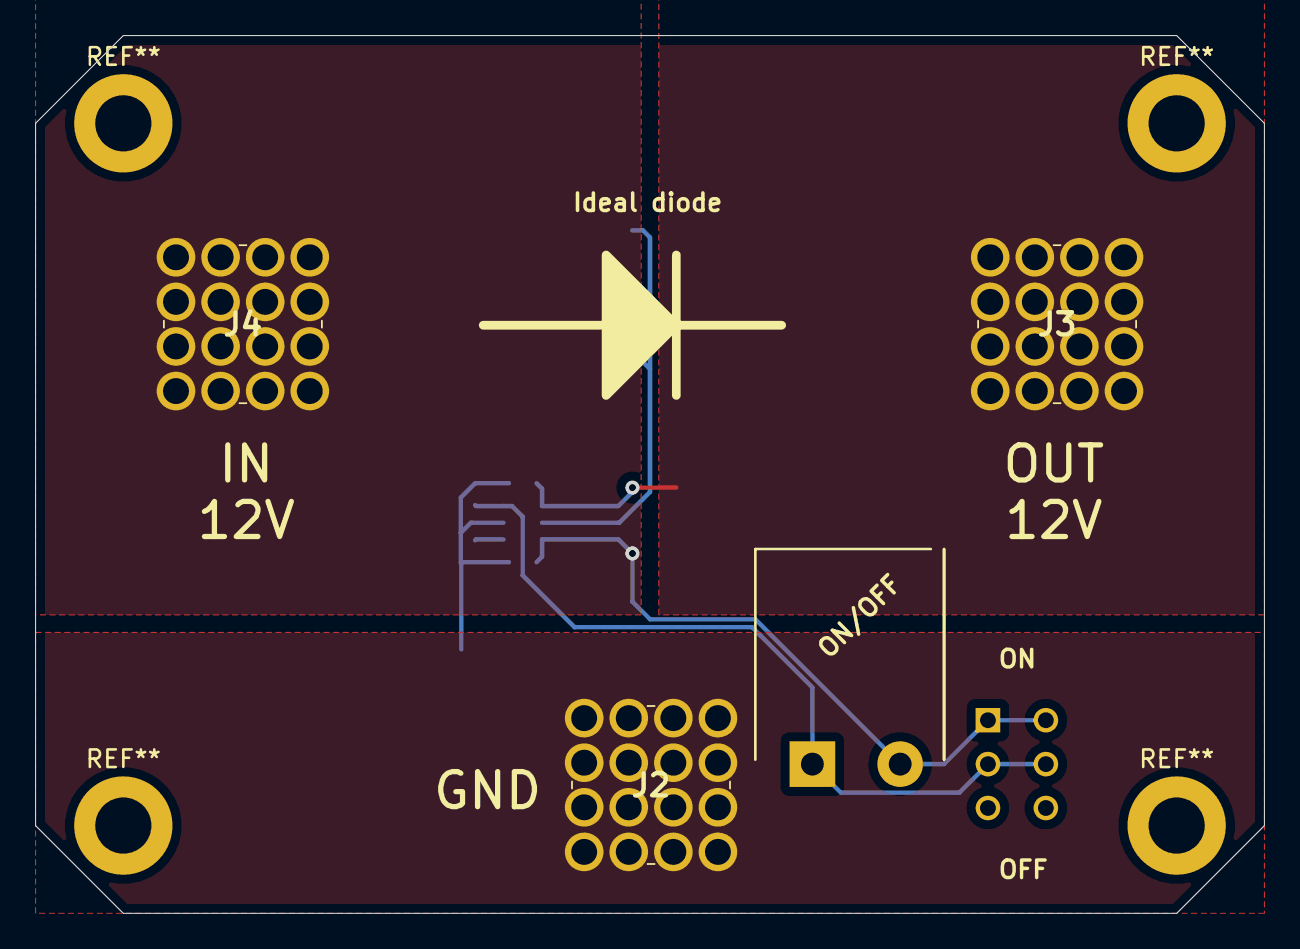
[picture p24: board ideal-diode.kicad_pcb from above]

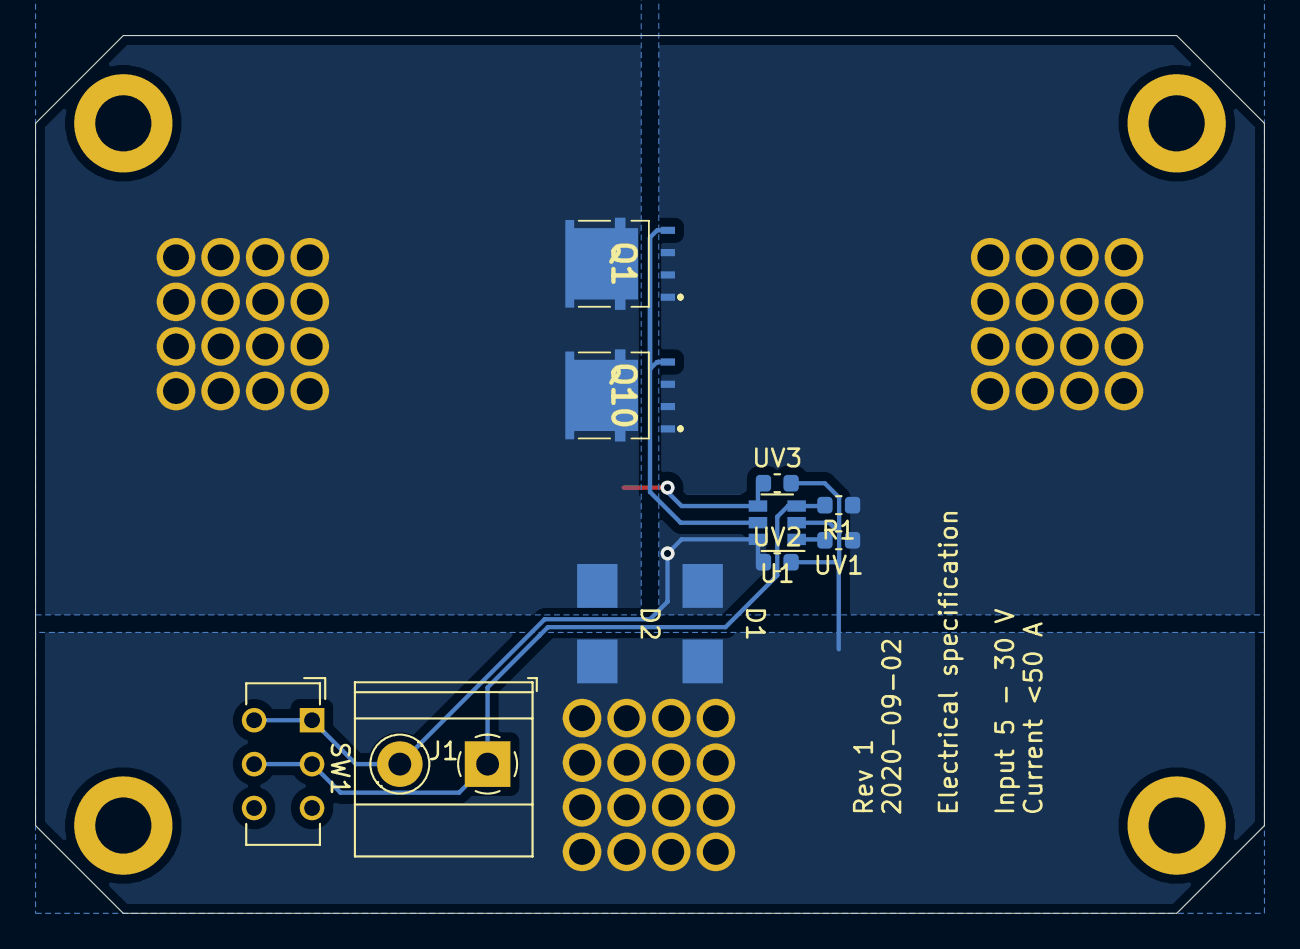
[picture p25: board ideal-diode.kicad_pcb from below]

Board: 2 copper layers, 70.0 x 50.0 mm, 14 parts (11 on the bottom side), 6 nets.

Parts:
D1, D2: D_TVS; D_SMB
J1: Enable; TerminalBlock_Phoenix_MKDS-1,5-2_1x02_P5.00mm_Horizontal
J2: M5 Ground; M5_7461383
J3, J4: M5 Output; M5_7461383
Q1, Q10: Q_NMOS_SGD; SQJA72EPT1_GE3
R1: DNP; R_0603_1608Metric
SW1: SW_DIP_x01; SW_CuK_JS202011CQN_DPDT_Straight
U1: LM74700; SOT-23-6
UV1, UV2, UV3: F; C_0603_1608Metric

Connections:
12V_in: D1.1, J1.2, J4.1, Q1.1, Q10.1, R1.1, SW1.1, U1.6, UV1.1, UV2.1
12V_out: D2.1, J3.1, Q1.3, Q10.3, U1.4, UV3.1
GND: D1.2, D2.2, J2.1, U1.2, UV2.2, UV3.2
Gate: Q1.2, Q10.2, U1.5
unnamed: J1.1, R1.2, SW1.2, U1.3
unnamed: U1.1, UV1.2

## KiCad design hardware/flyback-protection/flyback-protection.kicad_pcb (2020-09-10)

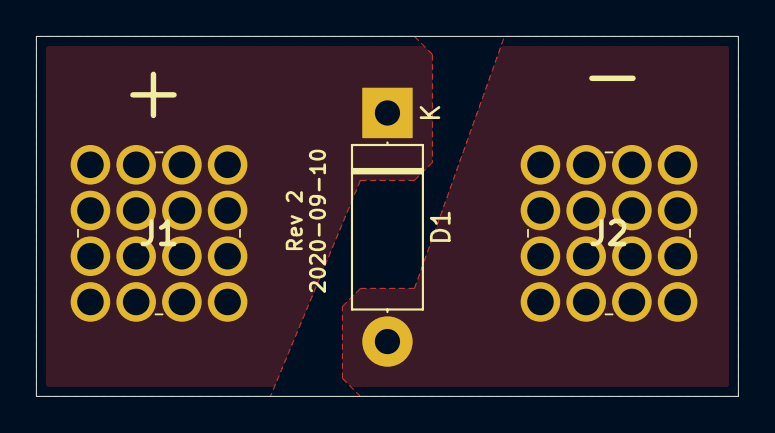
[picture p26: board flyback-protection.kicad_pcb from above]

Board: 2 copper layers, 39.0 x 20.0 mm, 3 parts (0 on the bottom side), 2 nets, no tracks yet.

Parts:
D1: D; D_5W_P12.70mm_Horizontal
J1, J2: M5; M5_7461383

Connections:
+12V: D1.1, J1.1
GND: D1.2, J2.1

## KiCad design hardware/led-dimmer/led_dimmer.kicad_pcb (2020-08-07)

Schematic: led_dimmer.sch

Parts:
C1, C3, C4, C5, C6: C_Small; C_0603_1608Metric
D1, D2: D_Small; D_SOD-123
F1: 5A; ATO_Fuseholder_3522-2
J1: USB_B_Micro; Microusb_105133-0011
J2: Screw_Terminal_01x04; TerminalBlock_Phoenix_MKDS-1,5-4_1x04_P5.00mm_Horizontal
Q3: Q_NMOS_GSD; SOT-23
Q4: Q_PMOS_GDS; TO-252-2
R1, R2: 10k; R_0603_1608Metric
R3, R6, R7, R8, R9: 1k; R_0603_1608Metric
R4: 100k; R_0603_1608Metric
R5: Dummy; R_0402_1005Metric
SW1: Rotary_Encoder_Switch; RotaryEncoder_Alps_EC11E-Switch_Vertical_H20mm
SWD1: SWD_TAGCONNECT; TAG_TC2030-IDC-NL
U1: ATSAMD21G18A-AUT; TQFP-48_7x7mm_P0.5mm
U2: LD1117S33TR_SOT223; SOT-223-3_TabPin2

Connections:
+3V3: C3.2, C6.1, R1.1, R2.2, R4.2, SWD1.1, U1.6 (VDDANA), U1.17 (VDDIO), U1.36 (VDDIO), U1.44 (VDDIN), U2.2 (VO)
+5V: D1.2 (A), J1.1 (VBUS)
+12V: D2.2 (A), F1.1, Q4.3 (S), R6.2, R8.1
A1_BATVOLT: R6.1, R9.2, U1.7 (PB08)
A2: U1.8 (PB09)
A3: U1.9 (PA04)
A4: U1.10 (PA05)
D0: U1.16 (PA11)
D1: U1.15 (PA10)
D2: U1.23 (PA14)
D3_LED: U1.14 (PA09)
D4_PMOS_SWA: U1.13 (PA08)
D5_ENCA: R1.2, SW1.A, U1.24 (PA15)
D8_LED_POWER: Q3.1 (G), R7.1, U1.11 (PA06)
D9_PMOS_SWA: U1.12 (PA07)
D10: U1.27 (PA18)
D11_ENCB: R2.1, SW1.B, U1.25 (PA16)
D13_ENC_SW: C1.1, R3.1, R4.1, U1.26 (PA17)
GND: C1.2, C3.1, C4.1, C5.2, C6.2, J1.5 (GND), J1.6 (Shield), J2.2, J2.3, Q3.2 (S), R5.1, R7.2, R9.1, SW1.C, SW1.S2, SWD1.5, U1.5 (GNDANA), U1.18 (GND), U1.35 (GND), U1.42 (GND), U2.1 (GND)
LED: J2.4, Q4.2 (D)
unnamed: C4.2, U1.43 (VDDCORE)
unnamed: C5.1, D1.1 (K), D2.1 (K), U2.3 (VI)
unnamed: F1.2, J2.1
unnamed: Q3.3 (D), Q4.1 (G), R8.2
unnamed: R3.2, SW1.S1
SCL: U1.32 (PA23)
SDA: U1.31 (PA22)
SWCLK: SWD1.4, U1.45 (PA30)
SWDIO: SWD1.2, U1.46 (PA31)
USB+: J1.3 (D+), U1.34 (PA25)
USB-: J1.2 (D-), U1.33 (PA24)
~RESET: R5.2, SWD1.3, U1.40 (~RESET)

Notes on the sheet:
12V if possible, otherwise 5V

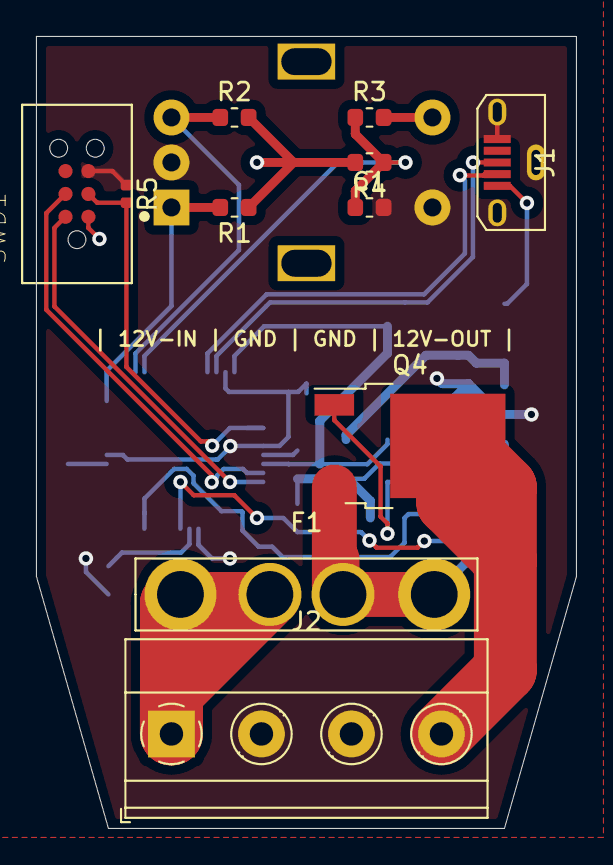
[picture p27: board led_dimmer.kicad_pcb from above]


Board: 2 copper layers, 30.0 x 44.0 mm, 25 parts (14 on the bottom side), 20 nets.

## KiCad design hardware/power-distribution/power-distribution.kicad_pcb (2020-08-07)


Board: 2 copper layers, 90.0 x 70.0 mm, 33 parts (0 on the bottom side), 18 nets.

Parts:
D1, D2, D3, D4: 2V; LED_0603_1608Metric
F1, F2, F3, F4: Fuse; ATO_Fuseholder_3522-2
J1, J2, J3: Parallell; PinHeader_1x02_P2.54mm_Vertical
J4, J6, J7, J8, J9: GND; M5_7461383
J5: 12V; M5_7461383
Q1, Q2, Q3, Q4: Q_PMOS_GDS; TO-252-2
R1, R2, R3, R4: 10k; R_0603_1608Metric_Pad1.05x0.95mm_HandSolder
R5, R6, R7, R8: 670R; R_0603_1608Metric
SWITCH_A1: Screw_Terminal_01x0; TerminalBlock_Phoenix_PT-1,5-2-5.0-H_1x02_P5.00mm_Horizontal
SWITCH_B1: Screw_Terminal_01x02; TerminalBlock_Phoenix_PT-1,5-2-5.0-H_1x02_P5.00mm_Horizontal
SWITCH_C1, SWITCH_C2: Screw_Terminal_01x02; TerminalBlock_Phoenix_PT-1,5-2-5.0-H_1x02_P5.00mm_Horizontal

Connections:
+12V: J5.1, Q1.3, Q2.3, Q3.3, Q4.3, R1.1, R2.1, R3.1, R4.1
/AOUT: D1.2, F1.1, J4.1
/BOUT: D2.2, F2.1, J7.1
/COUT: D3.2, F3.1, J8.1
/DOUT: D4.2, F4.1, J9.1
/G1: J1.1, Q1.1, R1.2, SWITCH_A1.1
GND: J6.1, R5.1, R6.1, R7.1, R8.1, SWITCH_A1.2, SWITCH_B1.2, SWITCH_C1.2, SWITCH_C2.2
unnamed: D1.1, R5.2
unnamed: D2.1, R6.2
unnamed: D3.1, R7.2
unnamed: D4.1, R8.2
unnamed: J1.2, J2.1, Q2.1, R2.2, SWITCH_B1.1
unnamed: J2.2, J3.1, Q3.1, R3.2, SWITCH_C1.1
unnamed: J3.2, Q4.1, R4.2, SWITCH_C2.1
SSR-A: F1.2, Q1.2
SSR-B: F2.2, Q2.2
SSR-C: F3.2, Q3.2
SSR-D: F4.2, Q4.2

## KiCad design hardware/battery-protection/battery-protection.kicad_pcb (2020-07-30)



Board: 2 copper layers, 70.0 x 70.0 mm, 22 parts (12 on the bottom side), 8 nets.

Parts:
D_LED_IN1: 2V; LED_0603_1608Metric
D_LED_OUT1: 2V; LED_0603_1608Metric
G_PD1: 10k; R_0603_1608Metric
J1: M6 Battery input; M6_7461098
J2: M5 Ground; M5_7461383
J3, J4, J5: M5 Output; M5_7461383
J6: CTRL; TerminalBlock_Phoenix_MKDS-1,5-6_1x06_P5.00mm_Horizontal
Q7, Q8, Q9, Q10, Q11, Q12: Q_NMOS_SGD; SQJA72EPT1_GE3
R_LED_IN1: 680R; R_0603_1608Metric
R_LED_OUT1: 680R; R_0603_1608Metric
SHDN_PD1: 10k; R_0603_1608Metric
U1: LTC4365TS8; SOT-23-8
UV1: 10k; R_0603_1608Metric
UV2: 470R; R_0603_1608Metric
UV3: 100pF; C_0603_1608Metric

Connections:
12V_in: J1.1, J6.1, J6.3, Q7.3, Q8.3, Q9.3, Q10.3, Q11.3, Q12.3, R_LED_IN1.1, U1.1, UV1.1
12V_out: J3.1, J4.1, J5.1, J6.5, Q7.1, Q8.1, Q9.1, Q10.1, Q11.1, Q12.1, R_LED_OUT1.1, U1.7
GND: D_LED_IN1.1, D_LED_OUT1.1, G_PD1.1, J2.1, J6.4, J6.6, SHDN_PD1.2, U1.3, U1.4, UV2.2, UV3.2
unnamed: D_LED_IN1.2, R_LED_IN1.2
unnamed: D_LED_OUT1.2, R_LED_OUT1.2
unnamed: U1.2, UV1.2, UV2.1, UV3.1
gate_driver: G_PD1.2, Q7.2, Q8.2, Q9.2, Q10.2, Q11.2, Q12.2, U1.8
~SHDN: J6.2, SHDN_PD1.1, U1.5

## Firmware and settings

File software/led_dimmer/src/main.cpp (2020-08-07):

#include <Arduino.h>
#include "settings.h"
#include "rotary.h"

void setup() {
  pinMode(PIN_DIMMER,OUTPUT);
  pinMode(PIN_BAT, INPUT);
  pinMode(PIN_ENCA,INPUT);
  pinMode(PIN_ENCB,INPUT);
  pinMode(PIN_SW,INPUT);
  Serial.begin(SERIAL_BAUDRATE);
  attachInterrupt(digitalPinToInterrupt(PIN_ENCA), readRotary, CHANGE);
  attachInterrupt(digitalPinToInterrupt(PIN_ENCB), readRotary, CHANGE);
  attachInterrupt(digitalPinToInterrupt(PIN_SW), readSwitch, LOW);
}

void loop() {
  
}

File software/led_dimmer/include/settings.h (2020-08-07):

#ifndef SETTINGS_H
#define SETTINGS_H

#define PIN_DIMMER 8
#define PIN_BAT A1
#define PIN_SW 13
#define PIN_ENCA 5
#define PIN_ENCB 11

#define SERIAL_BAUDRATE 9600

#define DIM(PWM) analogWrite(PIN_DIMMER,PWM)

extern u_int8_t dimPower;

#endif

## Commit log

2019-11-15 Added 6 relay and screw terminals.
    Added relay
    [Highside-powerdistribution.sch]
2019-11-15 Added equivalent P-Mosfet
    To avoid all clicking and less current draw.
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2019-11-16 Added power in sign.
    Added plus and minus sign
    [Highside-powerdistribution.kicad_pcb]
2019-11-17 Thicker traces and only +12V filled zones.
    The ground is returning over some other cable, not here.
    [Highside-powerdistribution.kicad_pcb]
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2019-11-17 Added 5x20 fuses on PCB
    [Highside-powerdistribution.kicad_pcb, Highside-powerdistribution.sch]
2019-11-17 Removed relay on schematic
    [Highside-powerdistribution.sch]
2019-11-18 Added serie connector
    To use one switch for multiple MOSFETs. Just a pinheader.
    [Highside-powerdistribution.kicad_pcb, Highside-powerdistribution.sch]
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2019-11-18 Moved resistor to create LP-filter from switch.
    Instead of a useless resistor on gate, now in LP-filter from switch.
    [Highside-powerdistribution.sch]
2019-11-18 Routed updated with LP filter
    [Highside-powerdistribution.kicad_pcb]
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2019-11-21 Changed Mosfet to SMD
    The cheap TH wasn't available at Farnell or RS.
    [Highside-powerdistribution.kicad_pcb, Highside-powerdistribution.sch]
2019-11-21 Rev 1.1
    - SMD Mosfet
    - Thicker traces
    [Highside-powerdistribution.kicad_pcb]
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2019-11-21 Changed fuses and added more 3D files.
    Changed to ATO fuses
    [Highside-powerdistribution.kicad_pcb, Highside-powerdistribution.sch]
2019-11-21 Changed to terminal block on input
    [Highside-powerdistribution.kicad_pcb, Highside-powerdistribution.sch]
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2019-11-26 Updated schematic with Powersplitter added
    Big commit with added powersplitter and updated power distribution board.
    [Highside-powerdistribution.kicad_pcb, Powerdistribution.kicad_pcb, Powerdistribution.sch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]
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2020-02-19 Moved filled zone to remove shortcurcit
    12V and the mosfets had filled zone together
    [Highside-powerdistribution.kicad_pcb, Powerdistribution.kicad_pcb, Powerdistribution.sch]
2020-02-19 Created a simply flyback protection for induction load
    [Flybackprotection.kicad_pcb, Flybackprotection.sch]
2020-02-29 Connect 12V for pullup resistor
    The pullup had lost connection to the 12V plane when changed the leads from fuses to the output.
    [Highside-powerdistribution.sch]
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2020-03-06 Changed to only pullup on no LP filter
    [power-distribution.sch]
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2020-03-12 Assign footprint to all parts and exported .net file
    [power-distribution.sch]
2020-03-12 Deleted old board and renamed ref-name on terminal block
    [power-distribution.sch]
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2020-03-16 Create a shore power circuit
    A 230V with 30 mA RCD and 16A circuit breaker to protect system.
    [shorepower.kicad_pcb, shorepower.sch]
2020-03-18 Create a MPPT solar circuit for lead acid batteries
    [mppt-solar-charger.kicad_pcb, mppt-solar-charger.sch]
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2020-03-20 Added a source selector for 230V
    If in future want a inverter and shore power, these two must newer connect together. A dual circuitbreaker make sure it never happen.
    [shorepower.sch]
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2020-04-04 Added two mosfets for pull both to GND.
    [led_dimmer.kicad_pcb, led_dimmer.sch]
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2020-07-04 Changed to 7.62 input pitch and 8 output with 2 and 2
    [power-distribution.kicad_pcb, power-distribution.sch]
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2020-07-08 Create 3D model of battery protection and cool block
    [battery_protection_COMPOUND.ipt, battery_protection_COMPOUND_1.ipt, battery_protection_COMPOUND_2.ipt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]
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2020-07-30 Changed to pd for mcu and added pinout for led
    [battery-protection.kicad_pcb, battery-protection.sch]
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2020-09-14 Create an ideal diode
    The ideal diode should be between bulk battery and start battery
    [ideal-diode.sch]
2020-09-14 Create an power connector with 3 M5 connector
    [power-connector.sch]
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2021-01-14 Created power distribution with only fuses and connectors
    [power-distribution-only-fuse.kicad_pcb, power-distribution-only-fuse.sch]
2021-02-03 Power distribution complete first order
    The board is finished and ordered.
    Added TVS diode to protect the board from transients.
    [BatteryIn.sch, Output.sch, power-distribution-complete.kicad_pcb]
2021-02-03 Created enclosure for ideal diode
    The ideal diode that should be between the house battery and start battery. Since only the house battery is charged with solar panels, the solar panel will now also charge the start battery, though i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
    [ideal_diode_COMPOUND.ipt, ideal_diode_COMPOUND_1.ipt, ideal_diode_C_0603_1608Metric.iam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]
2021-03-04 Changed UV resistor.
    The resistor now will make sure the battery is cut-off at
    20 - 30% SoC.
    [BatteryIn.sch]
2021-03-04 Added more resistor calculations.
    Added how to get 11.1 V as UV.
    This is below the voltage before the battery
    is destroyed. An AGM is able to handle
    a couple of these.
    [BatteryIn.sch]
2021-05-15 Create inline-dimmer
    A small circuit that uses 555 timer to dim a line.
    Both fuse holder mount or M5 solder pin.
    [TPS25940x-Q1.sch, fuseMIDIOutline.dxf, inline-dimmer.kicad_pcb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]
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2021-05-17 Created inline dimmer pot holder
    A simple PCB to hold a potentiometer and a screw terminal
    [inline-dimmer-pot.kicad_pcb, inline-dimmer-pot.sch]
